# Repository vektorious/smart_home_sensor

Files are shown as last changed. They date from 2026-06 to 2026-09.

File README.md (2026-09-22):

# Smart Home Sensor

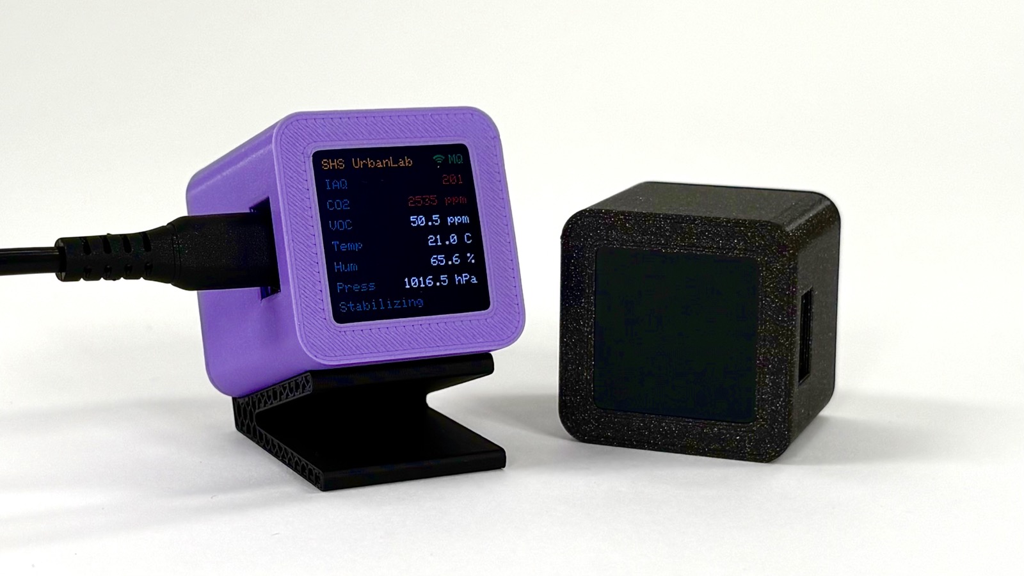
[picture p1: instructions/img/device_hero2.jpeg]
Finished Smart Home Sensor showing live readings on the colour display


An open hardware and firmware kit for a Wi-Fi-connected indoor air-quality sensor, built as a hands-on introduction to microcontroller programming, I2C sensors, air-quality processing, and connecting a DIY device to a smart home system. It is designed to be teachable in a workshop, but the device is meant to stay on a shelf afterwards and keep reporting.

The device reads a Bosch BME680 environmental sensor, runs Bosch's BSEC2 algorithm to derive an air-quality index, shows the live values on a colour display, and publishes them to [Home Assistant](https://www.home-assistant.io/) over MQTT or to the [diy-sensor.org](https://diy-sensor.org) dashboard. The backend is chosen by picking a firmware image at flash time.

Firmware can be built from source with the Arduino IDE, or flashed straight from the browser with the [web flasher](https://alexanderkutschera.com/smart_home_sensor/), which skips the toolchain entirely.

---

## Why This Exists

I wanted a workshop topic that touches sensors, microcontrollers, and IoT all at once, without turning into a semester course. This is the result: a one to two hour teaser that scratches the surface of a lot of things rather than going deep into any single one. None of it is novel, and that is fine. It is meant to be a good starting point.

The build is deliberately not hardwired. The BME680 hangs off four jumper wires, and the board is an ordinary ESP32-C6 with a display. If an air-quality sensor turns out not to be useful to someone, I hope the parts get pulled apart and turned into something else entirely. That would be the better outcome anyway.

---
## What the Device Does

A mains/USB-powered sensor that:
- Measures temperature, humidity, and barometric pressure
- Derives an Indoor Air Quality (IAQ) index, a CO₂-equivalent, and a breath-VOC estimate from the BME680's gas sensor via Bosch BSEC2
- Shows all readings live on the integrated 240×240 colour display, colour-coded by air quality
- Reports every reading to Home Assistant (where it can be charted, automated on, and turned into an "open a window" notification when the air gets stuffy), to plain MQTT topics, or to the diy-sensor.org dashboard, which needs no server of its own

There is no deep sleep and no battery: the live display and BSEC's multi-day gas-sensor self-calibration both need the device to run continuously.

---
## Hardware

- Waveshare ESP32-C6-LCD-1.3 microcontroller (ESP32-C6 + 1.3" ST7789 display)
- BME680 sensor module (temperature, humidity, pressure, gas / air quality)
- 4× Dupont wires (single wires or a 4-pin cable, either works)
- USB-C cable
- _Optional:_ 3D-printed enclosure ([`hardware/3d-print/`](hardware/3d-print/))

There is no custom PCB. The Dupont wires are soldered to the BME680 module's header pads, and their connectors then plug onto the board's pins, so the sensor-to-board link stays removable.

---

## Requirements

For any build:
- A computer with a USB-C port (or adapter)
- A 2.4 GHz Wi-Fi network (the ESP32-C6 will not see a 5 GHz-only network)
- A soldering iron, to solder the Dupont wires to the BME680 module (the only soldering in the build)

For flashing from the browser, that is the whole list: the web flasher needs a browser that supports Web Serial (Chromium, a recent Firefox, Chrome, Edge, or Opera; not Safari).

For the Home Assistant build, additionally:
- A running Home Assistant instance (a Raspberry Pi, mini-PC, or VM is fine)
- The Mosquitto broker add-on and the MQTT integration

To build from source instead of flashing a prebuilt image:
- The [Arduino IDE](https://www.arduino.cc/en/software) with the ESP32 board package and the libraries listed in the build instructions

---

## Documentation

| Guide | Covers |
| --- | --- |
| [`instructions/build_instructions.md`](instructions/build_instructions.md) | The standard build: wiring, browser flashing, setup portal, first readings |
| [`instructions/build_instructions_extended.md`](instructions/build_instructions_extended.md) | Building the firmware from source: Arduino toolchain, BSEC blob, MQTT and Home Assistant |
| [`instructions/background_information.md`](instructions/background_information.md) | BME680 + BSEC, IAQ / CO₂-equivalent / VOC, self-heating and offset calibration, MQTT vs ESPHome, similar projects |
| [`instructions/quick_reference/`](instructions/quick_reference/) | Printable two-page A5 summary |
| [`web-flasher/README.md`](web-flasher/README.md) | Building and publishing the firmware images |

---

## Firmware Variants

One Arduino sketch in [`code/shs_modular/`](code/shs_modular/) builds every image. They all share the display UI, the BSEC read path, and the setup portal, and differ only in where the readings go.

| Image | Reports to | Needs | Suited for |
| --- | --- | --- | --- |
| **diy-sensor.org** | [diy-sensor.org](https://diy-sensor.org), keyless | Wi-Fi | Running without a smart home system, using a hosted dashboard instead |
| **Home Assistant** | MQTT auto-discovery | Wi-Fi, MQTT broker | Keeping the device permanently in an existing smart home |
| **Display only** | nothing | nothing | Checking the hardware before dealing with a network |

Per-device values (device name, broker address, API key, publish interval, temperature offset) all live in the device's flash and are edited from a setup portal the device serves over its own Wi-Fi access point. Nothing needs recompiling per device.

### Workshop images

The build script can also produce a workshop image: the diy-sensor.org firmware with an event's defaults and API credentials compiled in, so the devices come up already pointed at the right dashboard and there is far less to configure on the day. The presets are only defaults, and the setup portal still overrides them. This is why the sketch builds four images rather than three. See [`web-flasher/README.md`](web-flasher/README.md) for how such an image is built and why its credentials stay out of the publicly served ones.

### ESPHome alternative

[`code/esphome/`](code/esphome/) holds an ESPHome configuration for the same hardware: native Home Assistant API, no broker, minimal display. Not yet verified on hardware.

---

## Repository Structure

```
code/
  shs_modular/             Firmware (Arduino + BSEC2 + display + backends)
    config.h               Pins, build variant, factory defaults — no credentials
    workshop_secrets.example.h  Template for the workshop API key (copy, gitignored)
    shs_modular.ino        Entry point
    settings.ino           Runtime settings in NVS + derived device identity
    portal.ino             Setup portal: Wi-Fi, settings, live readings, send test
    resetdetect.ino        Double-reset detection (re-opens the portal)
    display.ino            ST7789 UI
    bme680.ino             BME680 read path via Bosch BSEC2
    wifi.ino               Station connect + background reconnect
    mqtt.ino               MQTT: HA auto-discovery / flat topics / both
    sensorboard.ino        HTTPS publishing to diy-sensor.org
    utils.ino              Shared helpers
    bsec_config_33v_3s_4d.h  BSEC tuning blob (3.3 V, 3 s sample rate)
  esphome/
    smart_home_sensor.yaml Alternative ESPHome firmware
  legacy/
    test_wv_display/       Original display+sensor sketch (no networking, reference)

web-flasher/               Browser-based installer (ESP Web Tools) + build.sh

hardware/
  3d-print/                Enclosure parts (Main/thin body, lid, FreeCAD source)

instructions/
  build_instructions.md    Standard build guide — start here
  build_instructions_extended.md  Arduino toolchain, building from source, MQTT
  background_information.md Sensor theory, IAQ explained, MQTT vs ESPHome, system overview
  quick_reference/         One-page summary

img/                       Photos and diagrams (TODO)
```

---

## Licenses

| Component | License |
|---|---|
| Software (`code/`) | [MIT](LICENSE.code) |
| Hardware (`hardware/`) | [CERN-OHL-W 2.0](LICENSE.hardware) |
| Documentation (`instructions/`, `README.md`, `img/`) | [CC-BY 4.0](LICENSE.docs) |

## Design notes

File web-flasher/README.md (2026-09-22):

# Smart Home Sensor — Web Flasher

A browser-based installer built on [ESP Web Tools](https://esphome.github.io/esp-web-tools/).
Students open a page, pick a firmware, click **Connect**, and flash the board — no
Arduino IDE and no drivers.

## Files

| File | Purpose |
|---|---|
| `index.html` | The flasher page: firmware picker + install button |
| `manifest-workshop.json` | HPI Makeruniverse Welcome Workshop — keyed, time-limited |
| `manifest-sensorboard.json` | diy-sensor.org, keyless — the standard build |
| `manifest-ha.json` | Home Assistant over MQTT |
| `manifest-display.json` | Display only, no networking |
| `build.sh` | Builds all four images into `firmware/` |
| `vendor/` | ESP Web Tools, served from this site rather than a CDN (see `vendor/README.md`) |
| `firmware/*.bin` | Merged images (generated; gitignored on `main`) |

## The four images

All four come from the same sources in `code/shs_modular/`. None carries per-device
configuration: that lives in NVS and is entered in the setup portal after flashing,
which is what lets one image serve a whole room.

| Image | Build flags | Backend | Needs |
|---|---|---|---|
| **workshop** | `SHS_VARIANT=2` | diy-sensor.org, keyed | nothing — a Wi-Fi network |
| **sensorboard** | `SHS_VARIANT=2 SHS_NO_WORKSHOP_SECRETS` | diy-sensor.org, keyless | nothing |
| **ha** | `SHS_VARIANT=1` | MQTT auto-discovery | a broker + the HA MQTT integration |
| **display** | `SHS_VARIANT=3` | none | nothing |

`workshop` and `sensorboard` are the *same* variant and differ only in whether
`workshop_secrets.h` is compiled in — `SHS_NO_WORKSHOP_SECRETS` forces the keyless
build even on a machine that has the header, so both come out of one run of
`build.sh`. The include is also gated on `USE_SENSORBOARD`, which keeps the
credentials out of the `ha` and `display` images: those still copy
`DEFAULT_API_KEY` into settings, so without the gate the literal would be linked
into two binaries that have no use for it and are served publicly.

`build.sh workshop` refuses to run without `workshop_secrets.h` rather than quietly
producing an anonymous binary that calls itself the workshop image.

## Requirements (for whoever is flashing)

- A desktop browser with **Web Serial**: **Chromium**, a **recent Firefox**, Chrome, Edge, or Opera. It does not exist in older Firefox or
  Safari, or anywhere on iOS.
- The page must be served over **HTTPS** (or `http://localhost`). Web Serial refuses
  to run on plain `http://`.
- A USB-C **data** cable.

## Building the images

```bash
./build.sh                 # all four
./build.sh sensorboard     # just one
```

The script needs `arduino-cli` with the `esp32` core and the libraries listed in
[`instructions/build_instructions.md`](../instructions/build_instructions.md). It
creates the missing `esp32c6` BSEC blob automatically if a library update has
removed it — that failure otherwise surfaces as a bare linker error.

Each build is one merged image flashed at offset `0x0`; the ESP32 Arduino core emits
it as `shs_modular.ino.merged.bin`, so no `esptool merge_bin` step is needed. The
**Huge APP (3MB No OTA/1MB SPIFFS)** partition scheme is required — the default is
too small for BSEC.

After building, bump `"version"` in the matching manifest so returning users are
offered the update.

### Doing it by hand in the Arduino IDE

1. Set `SHS_VARIANT` in `config.h`.
2. Board **ESP32C6 Dev Module**, **Tools → Partition Scheme → Huge APP**.
3. **Sketch → Export Compiled Binary**, then copy `build/…/shs_modular.ino.merged.bin`
   to `web-flasher/firmware/shs-<image>.bin`. For the keyless build, add
   `SHS_NO_WORKSHOP_SECRETS` to the sketch's build flags or temporarily move
   `workshop_secrets.h` aside.

## Workshop image

The HPI Makeruniverse Welcome Workshop runs on **23–24 September 2026**.
Its dashboard project is `hpi-makeruniverse-welcome-workshop`, and its image
is scheduled for withdrawal on **1 October 2026**. Withdrawal is a manual
publication step; the date shown on the page does not remove the image automatically.

Built against the gitignored `code/shs_modular/workshop_secrets.h` (see
`workshop_secrets.example.h`), which bakes in an API key, the dashboard project, and
the salt each device derives its write key from.

**Why it carries a key at all.** Not for persistence — that is switched *off* for the
workshop policy. It is the per-IP limits: a class sits behind one NAT address, and the
anonymous policy allows 10 active devices, 5 new devices an hour, and 1,000 requests a
day. A keyless class of 80 boards would stop at the fifth. With a key those become
500 / 100 / 50,000.

**Treat it as a temporary artefact.** Anything in that header is inside a binary served
publicly, so `strings` recovers it in seconds. The **API key** is therefore effectively
published: anyone who downloads the image can write to the instance under the workshop
policy, and because the write budget is charged per credential they can drain the same
bucket the class draws from.

The **salt** is weaker than it looks, but not as weak as "the key is public":

- The write key is `HMAC-SHA256(salt, mac)` over the **full 48-bit MAC**, while the
  public device ID carries only the low 32 bits — and those are the OUI plus one NIC
  byte, the predictable part. A device ID therefore leaves 2^16 = 65,536 candidates,
  with no offline way to test one: each guess costs a POST. Under the per-IP limits
  that is hours per device and a wall of 403s in the ingest log.
- Proximity defeats it entirely. The ESP32's Wi-Fi station MAC **is** the base efuse
  MAC — the exact derivation input — broadcast in the clear in every frame. Anyone in
  radio range reads all 48 bits passively, without joining the network.

Inherent to deriving from the MAC; no salt scheme changes it, and it is the price of a
key that survives a flash erase so a student cannot brick their device ID. For a
classroom it is a prank vector, not a breach.

### Retiring it

The page states a withdrawal date, and the date is the point:

1. delete `manifest-workshop.json` and `firmware/shs-workshop.bin` from `gh-pages`,
   and drop the option from `index.html`;
2. remove the key from `API_KEYS` in the server `.env` and restart the service;
3. `python -m app.admin delete-key-data <sha256>` for anything left behind.

With `POLICY_<NAME>_PERSISTENT_DEVICES=false` step 3 is mostly a formality: the
devices expire 48 h after their last reading on their own.

**Set that policy before the first board claims its ID.** `persistent` is a column
stamped at creation (`routes/ingest.py`: `persistent=authenticated and
policy.persistent_devices`) and the sweep reads the column, not the current policy.
Applied afterwards it changes nothing for devices that already exist: they stay
persistent forever, are never swept, and their IDs never become claimable again
without deleting them by hand.

Students keep their hardware: the keyless **sensorboard** image stays on the page and
publishes to the same dashboard. It claims the same device ID, so if the workshop
device has not expired yet, paste the write key shown on the workshop portal page into
the keyless build's *Write key* field to adopt it. After expiry the ID is simply free
again.

## Hosting

GitHub Pages publishes from a branch root or `/docs`, not an arbitrary subfolder, so
the site lives on a dedicated `gh-pages` branch mirroring this folder at its root:

```
gh-pages/
├── index.html
├── vendor/                    # ESP Web Tools (26 files + LICENSE)
├── manifest-workshop.json
├── manifest-sensorboard.json
├── manifest-ha.json
├── manifest-display.json
├── .nojekyll
└── firmware/
    ├── shs-workshop.bin
    ├── shs-sensorboard.bin
    ├── shs-ha.bin
    └── shs-display.bin
```

The binaries live only on `gh-pages` — four 4 MB images per release would bloat
`main`'s history for no benefit, which is why `firmware/.gitignore` excludes them.

```bash
git worktree add /tmp/ghpages gh-pages
cp index.html manifest-*.json /tmp/ghpages/
cp -r vendor /tmp/ghpages/
cp firmware/*.bin /tmp/ghpages/firmware/
# bump "version" in the manifests you changed
git -C /tmp/ghpages commit -am "Update flasher firmware" && git -C /tmp/ghpages push
git worktree remove /tmp/ghpages
```

## Local testing

```bash
python3 -m http.server 8000
# open http://localhost:8000 — localhost counts as secure for Web Serial
```

## Setup AP names

The commissioning AP uses a deterministic, friendly name such as
`SHS-Sparkly-Capybara`. The adjective and noun are selected from the ESP-IDF
base MAC, so the same board gets the same name after reboot while boards with
different base MACs normally get different names. The generated name is used
only for the temporary setup AP; the persisted device name and dashboard name
are unchanged.

The word lists are original project content and live in
`code/shs_modular/ap_names.h`. They are compiled into flash and contain no
external data or runtime dependency.

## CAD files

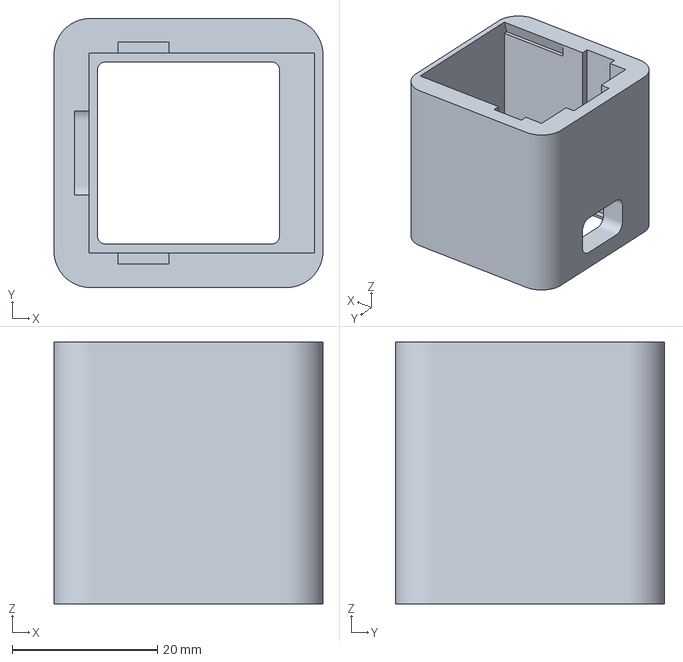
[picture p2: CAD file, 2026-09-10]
hardware/3d-print/SmartHomeCube-Main.3mf
37.0 x 37.0 x 36.0 mm

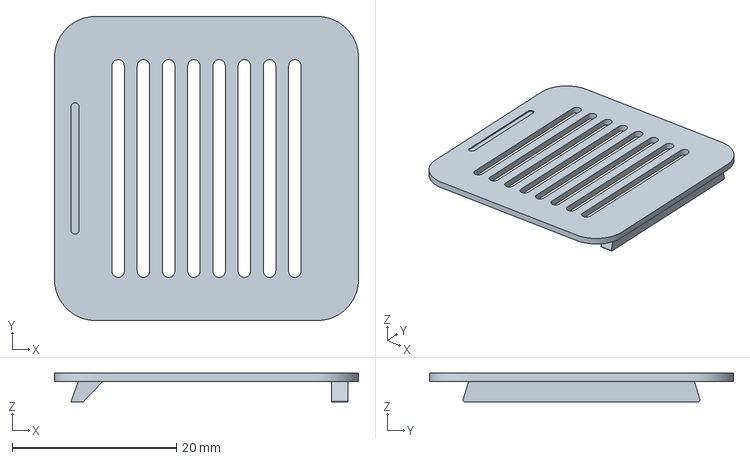
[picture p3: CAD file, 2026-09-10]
hardware/3d-print/SmartHomeCube-Lid.3mf
37.0 x 37.0 x 3.50 mm

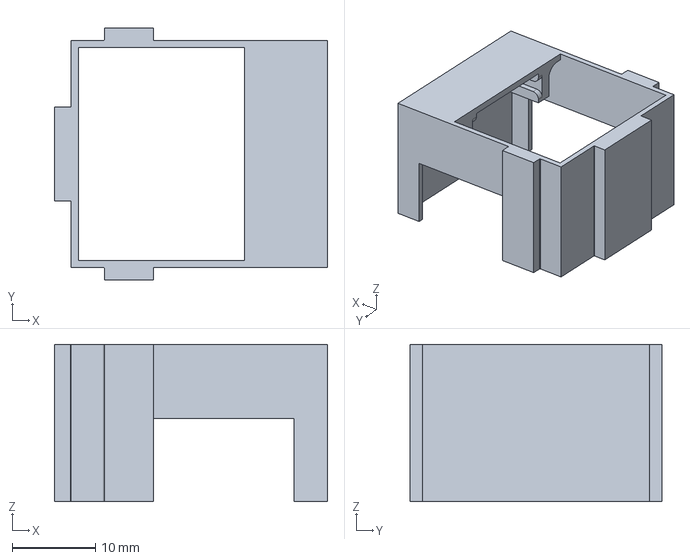
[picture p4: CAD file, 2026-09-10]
hardware/3d-print/src/SmartHomeCube.FCStd
32.8 x 30.3 x 18.9 mm

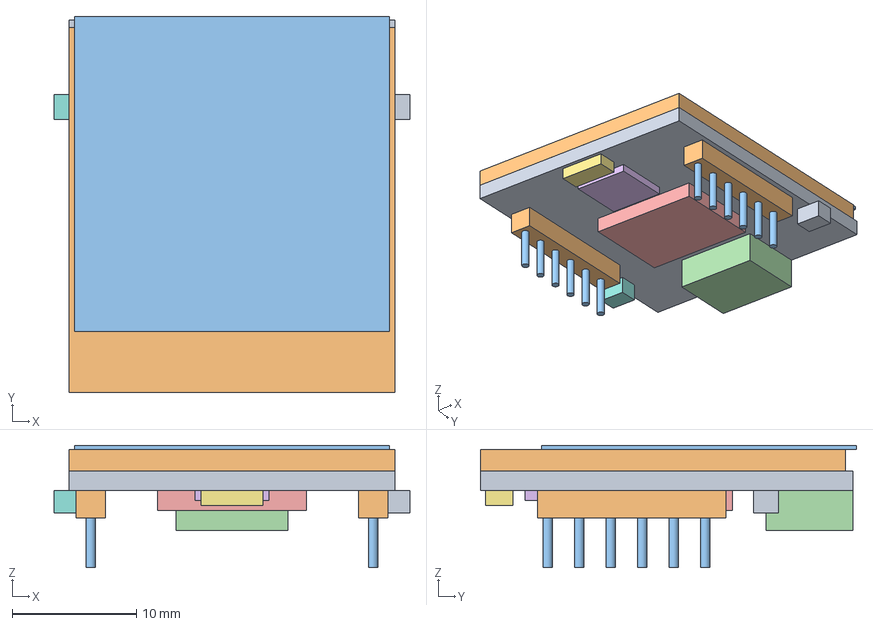
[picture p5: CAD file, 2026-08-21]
hardware/3d-print/src/ESP32-C6-LCD-1.3-M.FCStd
28.6 x 30.3 x 9.85 mm
PCB
LCD frame
LCD glass
USB-C connector
MicroSD slot
ESP32-C6FH4
Ceramic antenna
RESET button
BOOT button
Header plastic
Header pins
M2 mounting holes

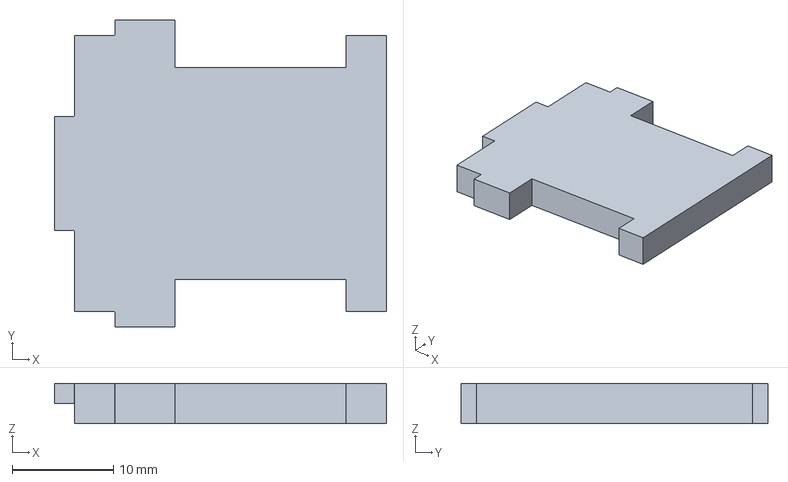
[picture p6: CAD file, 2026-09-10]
hardware/3d-print/SmartHomeCube-Inlay_mid.3mf
32.8 x 30.3 x 4.00 mm

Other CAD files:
hardware/3d-print/SmartHomeCube-Inlay_top.3mf

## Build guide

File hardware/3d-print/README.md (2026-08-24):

# 3D-Printed Enclosure

An enclosure for the Waveshare ESP32-C6-LCD-1.3 + BME680 that keeps the display visible,
gives the BME680 airflow while shielding it from the warm side of the board, and routes the
USB-C cable for permanent powered operation.

## Assembly

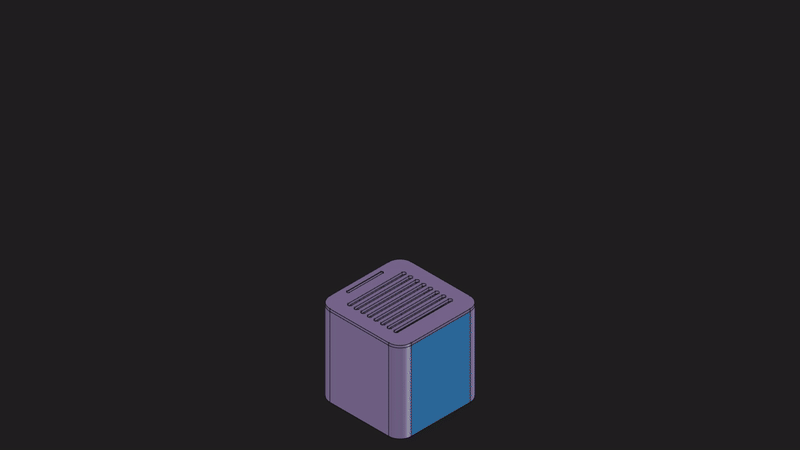
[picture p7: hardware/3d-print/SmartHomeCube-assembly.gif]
Exploded assembly animation


The enclosure is assembled from bottom to top in this order:

1. Main housing
2. ESP32-C6-LCD-1.3-M
3. Lower inlay
4. Upper inlay
5. Lid

The higher-quality MP4 version is available as [`SmartHomeCube-assembly.mp4`](SmartHomeCube-assembly.mp4).

## Parts

| File | Description | |
|---|---|---|
| `SmartHomeCube-Main.3mf` | Main body | required |
| `SmartHomeCube-Inlay.3mf` | Lower inlay, sits on the board and carries the sensor above it | optional |
| `SmartHomeCube-Inlay_top.3mf` | Upper inlay, holds the BME680 under the lid opening | optional |
| `SmartHomeCube-Lid.3mf` | Lid | required |

The two inlays position the BME680 above the board and away from its heat. Without them the sensor still works, but something insulating should go between board and sensor instead, for example the styrofoam packing piece the ESP32 board ships with.

Print with standard PLA settings; no supports needed.

## Modifying the fit

The FreeCAD source is in `src/SmartHomeCube.FCStd`. All clearances and offsets are exposed in
the **Variable set** (`Model → Variable set`) so you can adjust them for a tight fit without
touching the geometry directly.

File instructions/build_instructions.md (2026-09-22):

# Build Instructions: Smart Home Sensor

This is the standard build. You solder four wires to the BME680, connect it to the board, flash a prebuilt firmware image from your browser, and configure the device through its own setup page. No Arduino IDE, no libraries and no account needed.

**What you need:**

The ESP board, the BME680, four Dupont wires, a USB-C data cable, a soldering iron, and a laptop running a browser that supports Web Serial: Chromium, a recent Firefox, Chrome, Edge, or Opera. Older Firefox versions do not have it, and neither does Safari or anything on an iPad.

---

## 1. Collect all parts

**Electronics**

- Waveshare ESP32-C6-LCD-1.3 microcontroller (ESP32-C6 + 1.3" ST7789 display)
- BME680 sensor module
- 4× Dupont wires (single wires or a 4-pin cable, either works)
- USB-C data cable (a charge-only cable cannot flash the ESP, and they look identical)

**Optional**

- 3D-printed enclosure, see [`hardware/3d-print/`](../hardware/3d-print/)

**Tools**

- A computer with a USB-C port
- Soldering iron and solder

---

## 2. Wire the sensor

The BME680 talks to the board over **I2C**: two data lines plus power and ground.

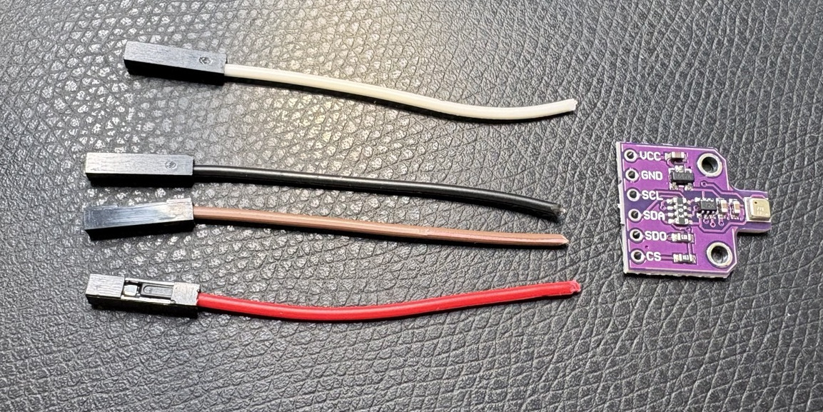
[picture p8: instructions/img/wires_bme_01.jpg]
Four Dupont wires and the BME680 module before assembly


Cut one end off each Dupont wire and strip about 3 mm of insulation. Twist the exposed copper strands together. Keep the female socket on the other end; it plugs onto the board's header pins.

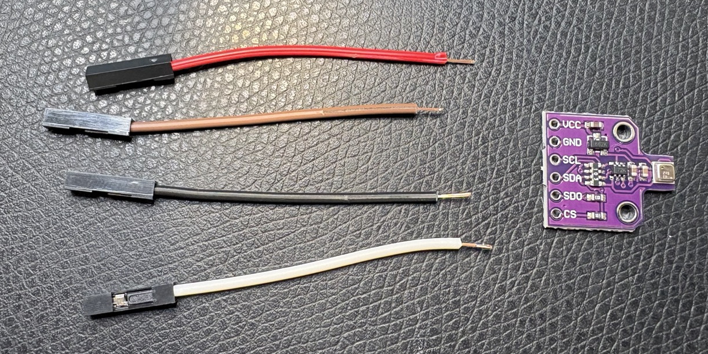
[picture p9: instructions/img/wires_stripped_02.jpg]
The four wires cut and stripped, ready to solder


Use the four pads labelled **VCC, GND, SDA, and SCL**. Push each stripped end through its hole **from the back**, the plain side without the components, and bend it flat against the labelled front so the wire runs off the side edge of the module, in the plane of the board. Soldering them this way keeps the wires out of the way of both the sensor and the enclosure.

<div align="center">

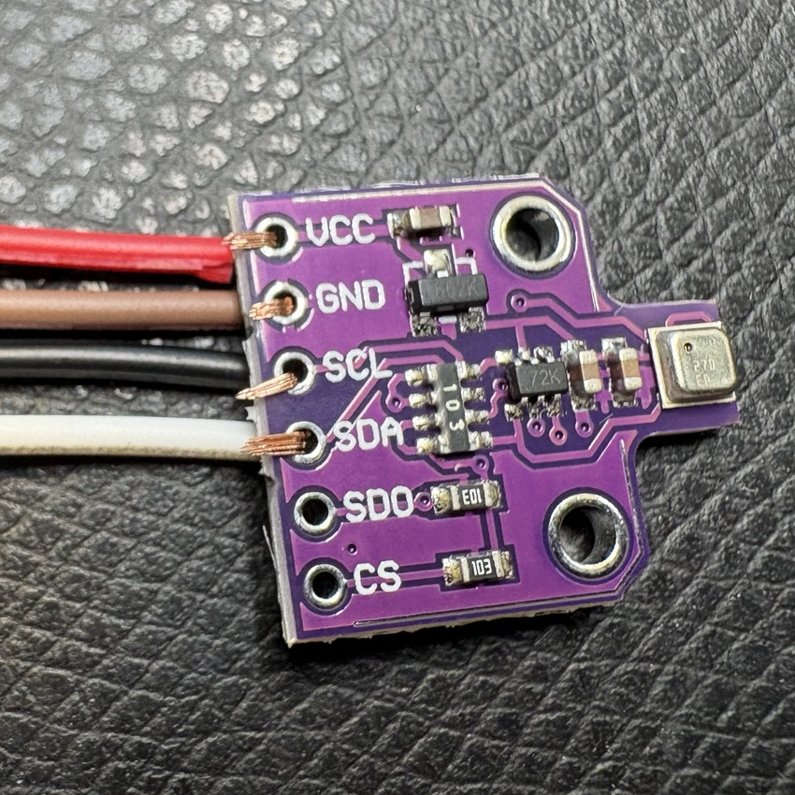
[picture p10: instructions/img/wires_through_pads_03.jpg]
Stripped wire ends pushed through the pad holes and bent flat, before soldering


</div>

Solder each joint on that labelled side, then snip off anything sticking out past the pad.

<div align="center">

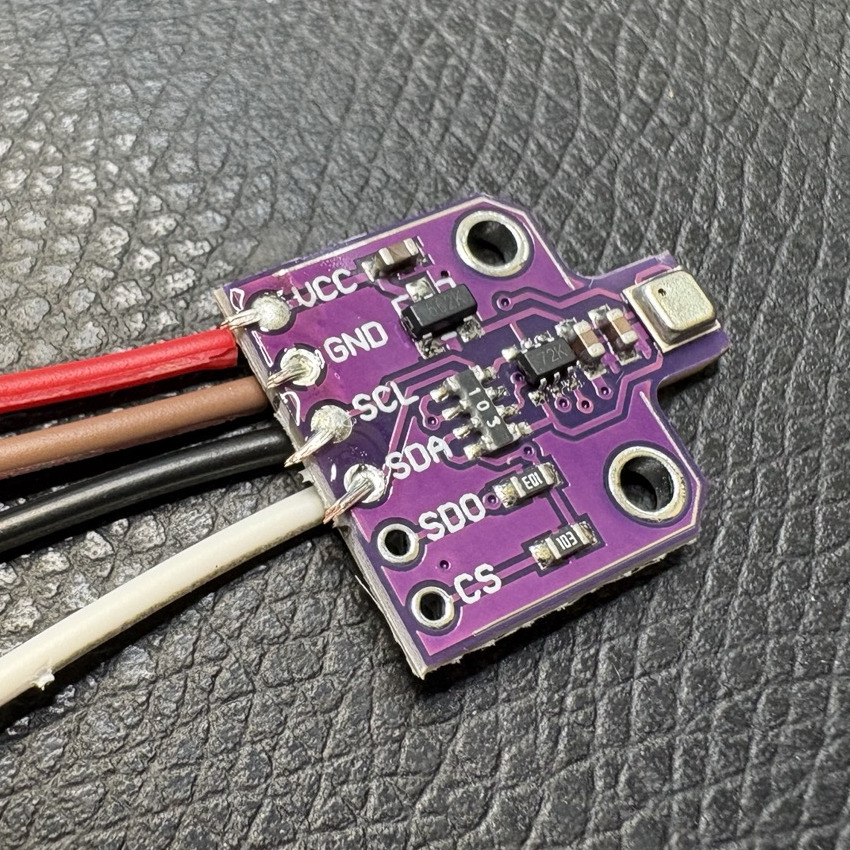
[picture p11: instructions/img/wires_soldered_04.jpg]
The four wires soldered to the BME680 pads, wires leaving flat to the side


</div>

<div align="center">

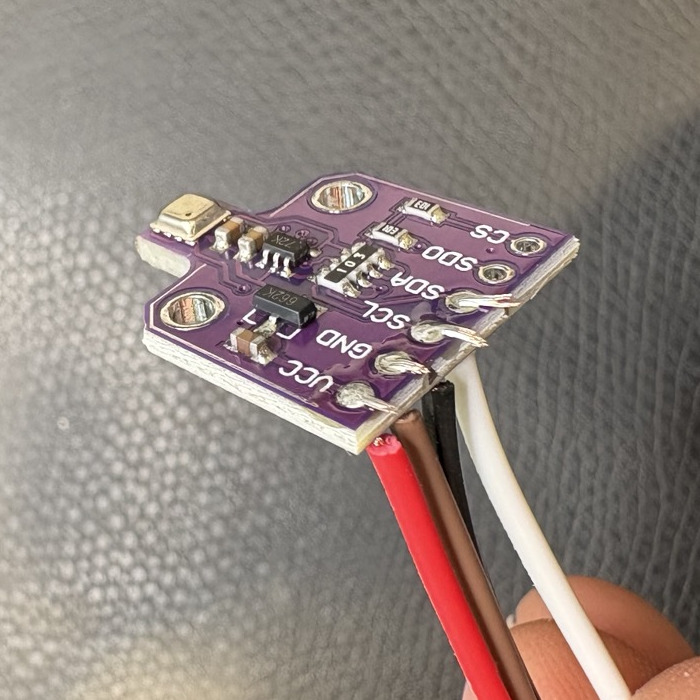
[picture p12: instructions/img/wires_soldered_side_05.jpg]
Side view of the soldered joints, showing the wires staying in the plane of the module


</div>

Then push the four sockets onto the matching pins on the board. Only the sensor side is soldered, so the sensor-to-board link stays removable and the board can be reused for something else later.

Before plugging in the USB cable, check that VCC connects to **3V3, not 5V**, and that SDA and SCL are not swapped. Swapping those two signal wires is a common reason the board cannot detect the sensor.

| BME680 pin | VCC | GND | SDA | SCL |
| --- | --- | --- | --- | --- |
| Board pin  | 3V3 | GND | GPIO 3 | GPIO 2 |

<div align="center">

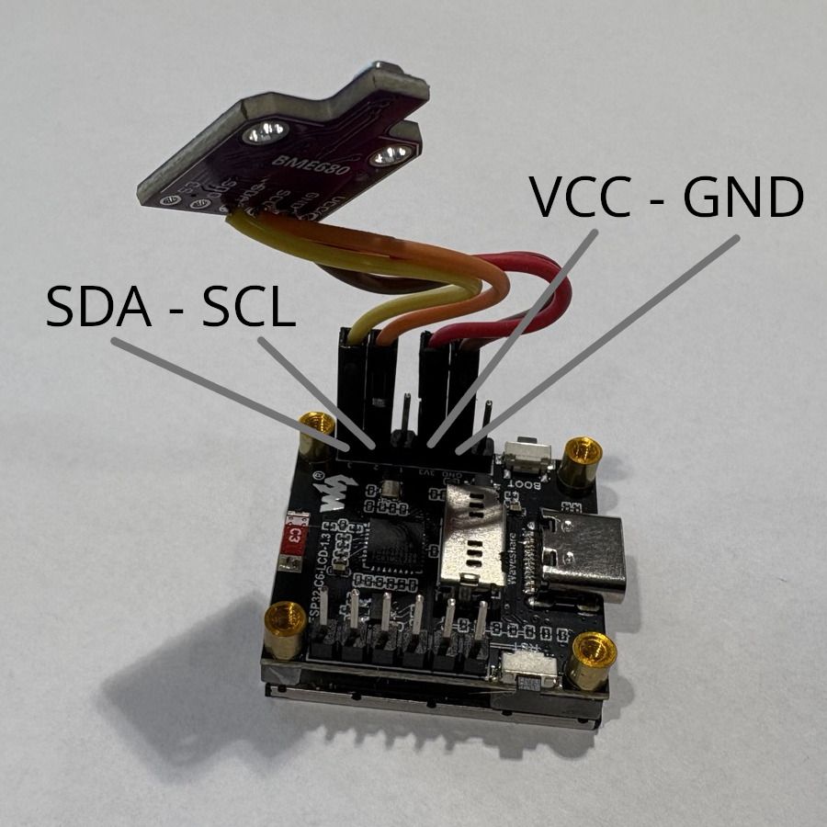
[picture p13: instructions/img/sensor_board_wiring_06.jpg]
BME680 sensor connected to the board, with the SDA/SCL and VCC/GND connections labelled


</div>

---

## 3. Flash and test the sensor

Before putting the board into the enclosure, flash it and verify that the wired BME680 is working. Wiring problems are much easier to fix while the board and sensor are still accessible.

1. Open the [web flasher](https://alexanderkutschera.com/smart_home_sensor/).
2. Pick an image. In a workshop, choose the one your instructor recommends: it usually carries the event's dashboard settings already, so there is less to fill in later. Otherwise pick **diy-sensor.org** to publish to the public dashboard, or **Home Assistant (MQTT)** if you already run Home Assistant with an MQTT broker.
3. Plug the board into your laptop with a USB-C data cable.
4. Click **Connect**, choose the port named `USB JTAG/serial debug unit`, and click **Install**. It takes about a minute.

If the port list is empty, start the board in flashing mode: unplug it, hold **BOOT**, plug the cable back in while holding the button, then release it after about 2 seconds. If the board still does not appear, try another USB data cable.

When flashing finishes, let the board boot with the sensor still connected. On the setup display, wait for the **BME680 sensor** indicator to show green **OK**. It may show **checking...** or **warming up** first. That is all you need to check at this stage; you will look at live readings after setup.

> **Stop here if the sensor is not detected.** Switch off USB power and re-check the wiring: 3V3 (not 5V), GND, SDA → GPIO 3, and SCL → GPIO 2. Reseat the connectors and test again. Do not put the board into the enclosure until this check passes.

---

## 4. Assemble the enclosure

If you printed the enclosure, assemble it now. It keeps the display visible and holds the BME680 above the board, away from the heat the ESP32 and the backlight give off, which can otherwise distort the temperature and humidity readings (see [`background_information.md`](background_information.md)).

Exploded assembly animation

<div align="center">

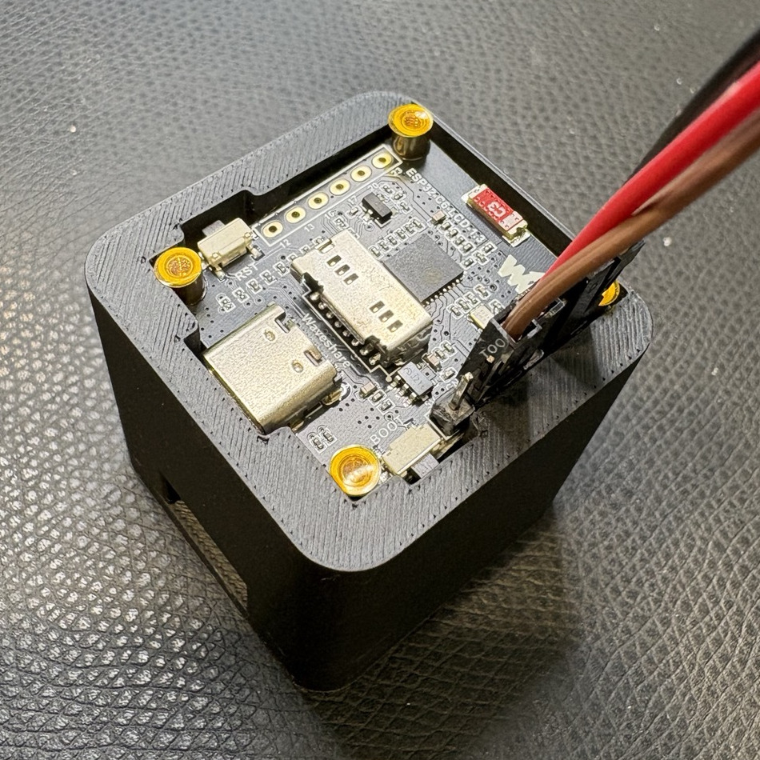
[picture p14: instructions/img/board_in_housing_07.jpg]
BME680 connected to the Waveshare board, which is resting on the open enclosure


</div>

Assemble from bottom to top:

1. **Main housing**: the outer body.
2. **ESP32-C6-LCD-1.3 board**: display facing the open front.
3. **Lower inlay**: separates the board from the sensor above it.
4. **Upper inlay**: holds the BME680 under the lid.
5. **Lid**: snaps on, but does not drop straight down. See *Closing the lid* below.

The two inlays are optional. In any case, put something insulating between the board and the sensor: the small piece of styrofoam the ESP32 board ships with does the job, so keep it when you unpack the board.

**Board and lower inlay.** Drop the board into the main housing with the display facing the open front (the bottom), and feed the sensor wires out past it. Lay the lower inlay on top of the board, then press board and inlay down together until they sit at the bottom of the housing. Leave the BME680 itself outside for now.

<div align="center">

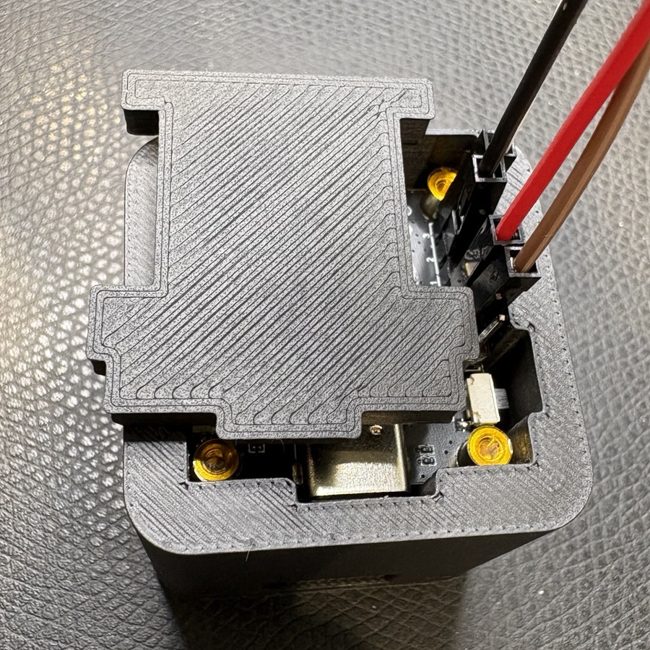
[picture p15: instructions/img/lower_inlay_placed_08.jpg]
Lower inlay laid on top of the board, both still standing proud of the housing


</div>

<div align="center">

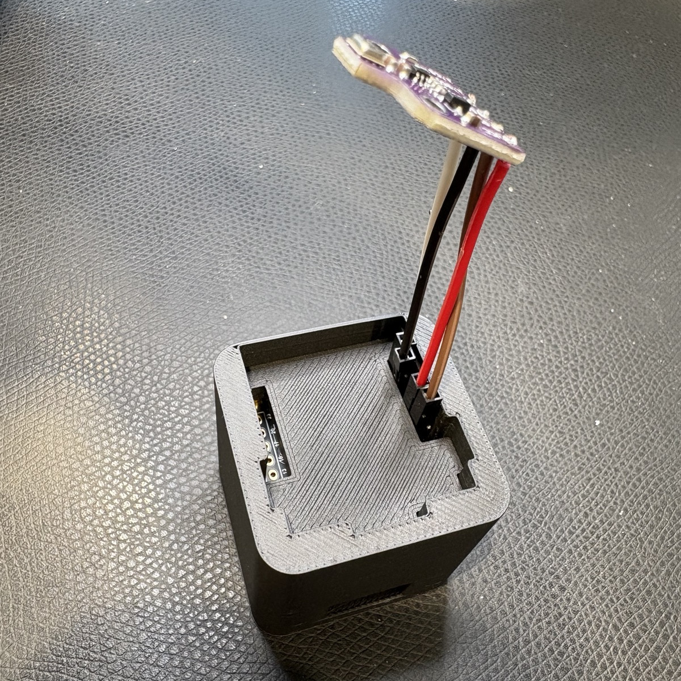
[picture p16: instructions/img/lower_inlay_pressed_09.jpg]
Board and lower inlay pressed further in, the sensor still hanging outside


</div>

<div align="center">

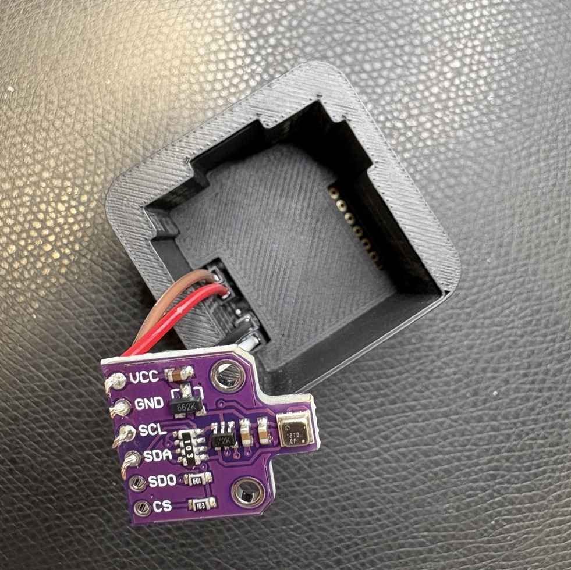
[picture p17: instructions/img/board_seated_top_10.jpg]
Top view with board and lower inlay seated at the bottom, sensor still out


</div>

**Sensor and upper inlay.** The BME680 drops into the recess in the upper inlay with its **component side facing up**, towards the lid grille, so the sensor breathes room air instead of the air trapped over the board. The wires leave through the side opening.

<div align="center">

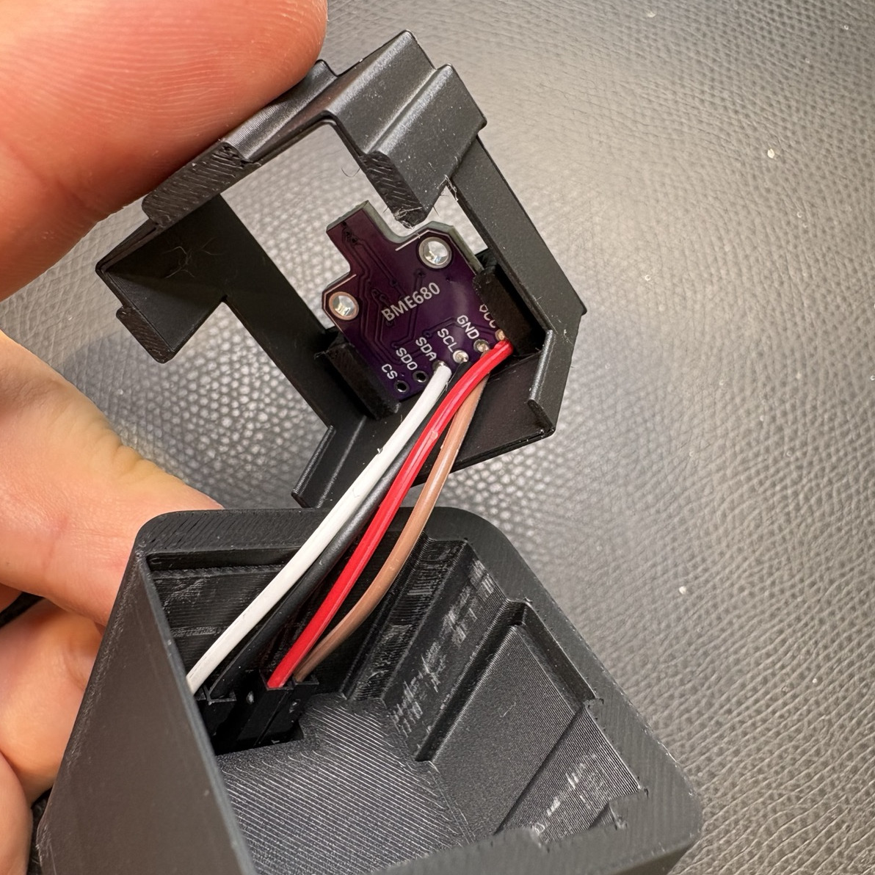
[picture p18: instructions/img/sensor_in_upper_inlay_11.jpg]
BME680 seated in the upper inlay, component side towards the lid, wires led out the side


</div>

Lay the styrofoam over the back of the sensor. It fills the space between sensor and board and reduces heat transfer from the ESP32.

<div align="center">

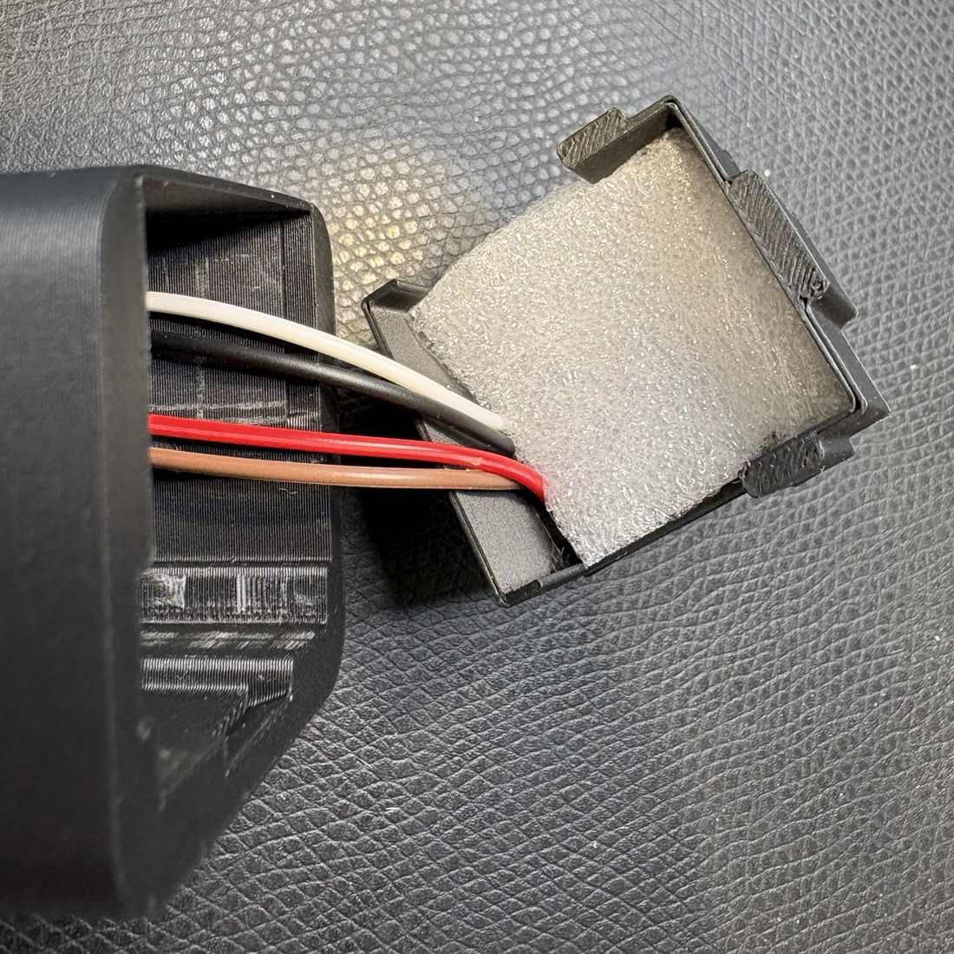
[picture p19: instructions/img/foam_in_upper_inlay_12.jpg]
Styrofoam laid into the upper inlay behind the sensor as a heat shield


</div>

Now lower the whole upper inlay into the housing, tucking the slack wire in as you go, and press it down until it sits flush.

<div align="center">

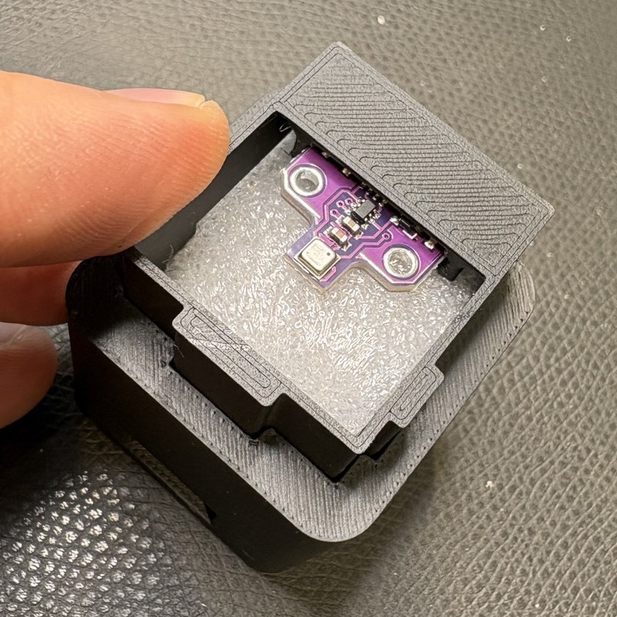
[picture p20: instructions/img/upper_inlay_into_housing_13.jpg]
Upper inlay with sensor and foam going into the main housing


</div>

<div align="center">

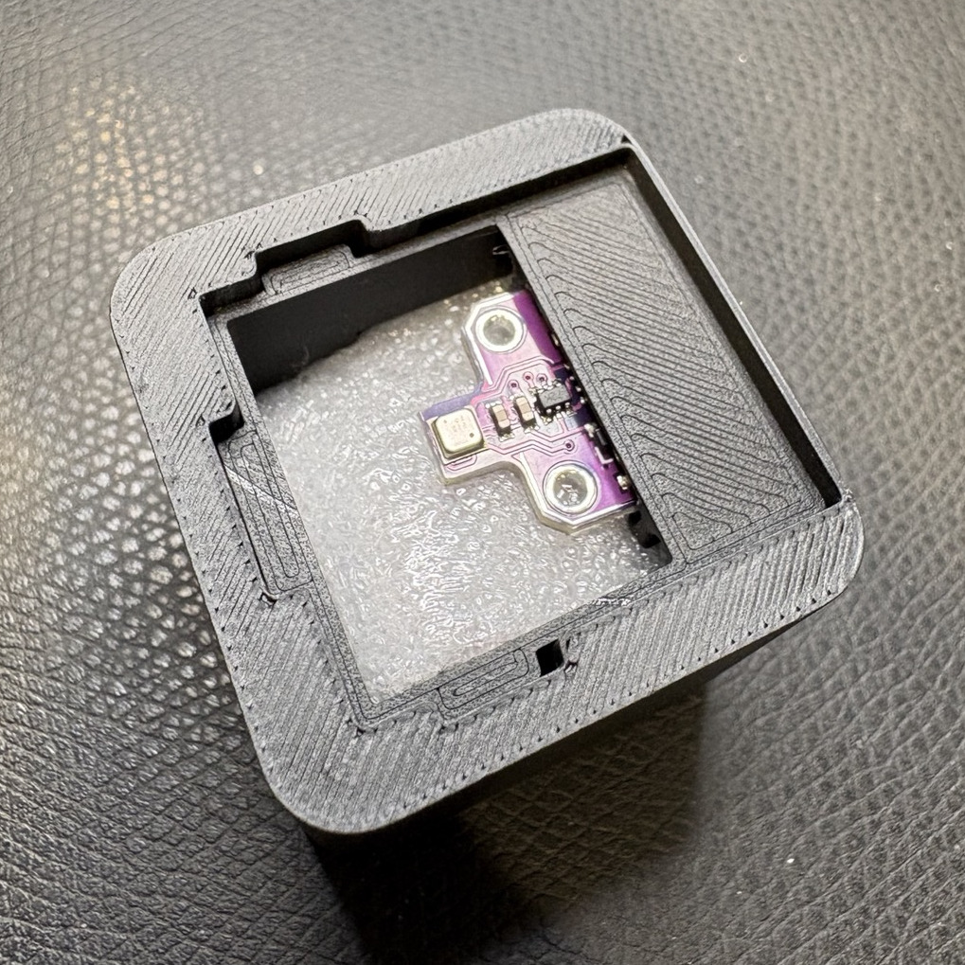
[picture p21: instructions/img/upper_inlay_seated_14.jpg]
Upper inlay seated, sensor facing up ready for the lid


</div>

**Closing the lid.** The lid does not press on from straight above. One edge carries a long tab, the opposite edge a short one, and they go in one after the other. Hold the lid at a slight angle, as in the photo, and slide the long tab into the two rails inside the main body. With that edge held in the rails, lower the other edge until the short tab snaps into its notch and the lid sits flush. To open it again, release the short tab first and then draw the long tab back out of the rails, rather than prying the lid straight up.

<div align="center">

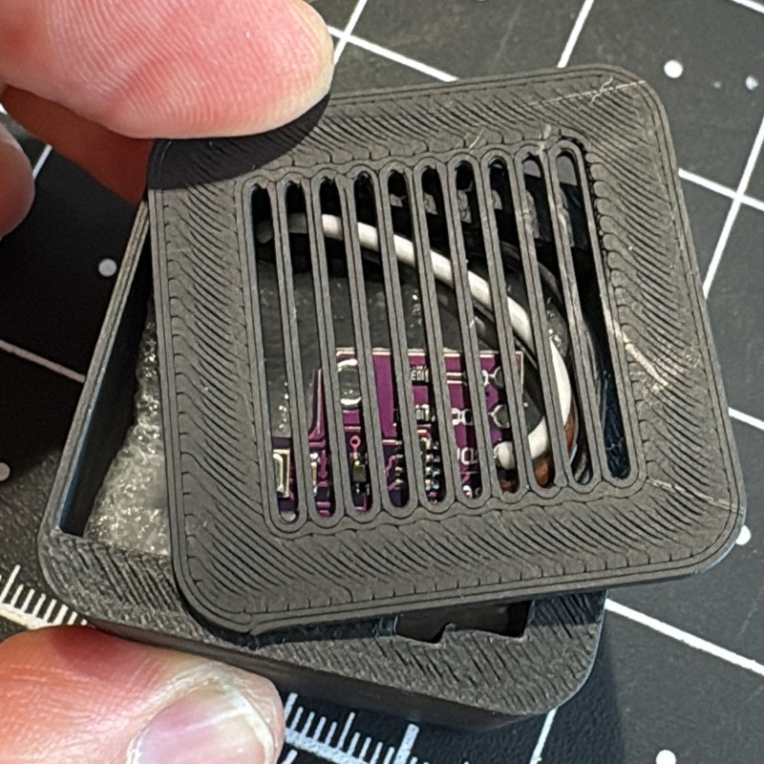
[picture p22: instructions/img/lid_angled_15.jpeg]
Lid held at an angle, its long tab going into the rails in the main body first


</div>

<div align="center">

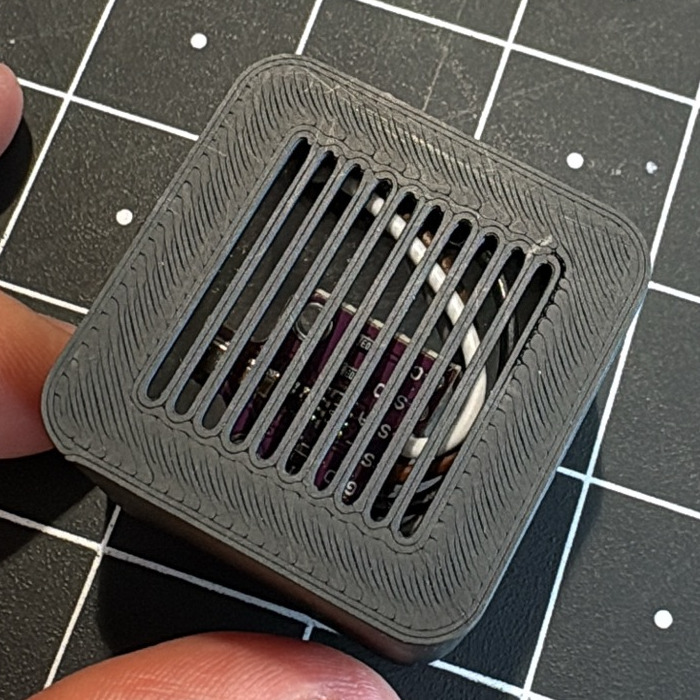
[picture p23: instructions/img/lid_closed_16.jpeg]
Lid closed flush, the BME680 visible through the grille


</div>

Once closed, the BME680 sits directly beneath the lid grille, exposed to room air rather than to heat from the board.

*(Some parts in these photos were printed in a different colour than the rest of the enclosure.)*

Print files and FreeCAD source: [`hardware/3d-print/`](../hardware/3d-print/).

---

## 5. Set it up

The board is already flashed and the sensor was checked in step 3. After assembling the enclosure, reconnect USB power. The display shows **Setup mode** with a Wi-Fi network name and an address.

1. On your laptop or phone, join the Wi-Fi network shown on the display. It has a friendly name such as **`SHS-Bouncy-Alpaca`**. It has no password.
2. A setup page should open by itself. If not, browse to **`192.168.4.1`**.
3. Tap **Configure WiFi**, pick the network, enter the password, and save. Every page here is served by the sensor itself, so give it a few seconds. Saving the Wi-Fi credentials takes longer because the board connects to the selected network. Tapping a second time only queues a second request. If your network is missing, check that it supports **2.4 GHz**. The ESP32-C6 cannot connect to a 5 GHz-only network.
4. Go back to the setup page and open **Setup** to give your device a **name**. On a shared dashboard this is what everyone else sees, so make it recognisable. Save.
5. Open **Live readings & connection test** and press **Send a test reading**.

On a diy-sensor.org image, a green **✓ 201** with **reading stored** means the server accepted your reading and the device is ready. Press the button again and you will see **200** instead: 201 means the device claimed its ID with that first reading, 200 that it added another. Both mean stored.

On a Home Assistant image, enter the broker host, port, and credentials under **Setup** and save them before sending a test reading. The test checks the connection to your broker. Further MQTT instructions are in [`build_instructions_extended.md`](build_instructions_extended.md).

Press **Finish setup** when the test passes. The portal also closes on its own after 10 minutes.

> Your **device ID** is printed on the display and on the setup page. The default ID is derived from the chip and stays the same across resets and reflashes. You can override it under **Setup**; a factory reset restores the default ID.

> **To change a setting later**, press **RESET twice in quick succession**. The display tells you when the window is open, then setup mode returns. This is how you move the device to another network, correct the temperature offset, or point it somewhere else, without reflashing.

> ⚠️ **The current enclosure covers the RESET button.** Until a revised case opens it up, reaching it means sliding the board out of the housing. You can also enter setup without using the button: at power-up, the device opens setup mode if it cannot connect to a saved Wi-Fi network. Power it up out of range of the saved network, or with that network switched off. Then join the setup Wi-Fi network shown on the display. (A network that drops *while* the device is running does not reopen setup; it reconnects in the background instead.)

---

## 6. Find your readings

**diy-sensor.org images:** go to `diy-sensor.org/dashboard/device/<your-device-id>`, or find your device name in the project your instructor points you at.

**Missed the QR code or don’t know your device ID?** You can always open [diy-sensor.org/dashboard](https://diy-sensor.org/dashboard) and look for your device by the name you gave it during setup. Select it to open its readings.

**Home Assistant images:** the device appears by itself under *Settings ▸ Devices & Services ▸ MQTT*, with entities for IAQ, IAQ Accuracy, CO₂ equivalent, Breath VOC equivalent, Temperature, Humidity, and Pressure.

Readings are sent every **5 minutes** by default, so the first chart takes a little patience. The display updates every few seconds regardless, which is where to look for an immediate reaction. You can shorten the interval in the setup page, but on a shared workshop key every device's readings come out of the same budget, so leave it unless you have a reason.

---

## 7. Now make it read something

The gas sensor is the interesting part, and it needs to warm up. Try these while it does:

- **Breathe on the sensor** from a few centimetres away and watch VOC and CO₂-equivalent climb, then fall back over a minute or two.
- **Compare temperature** against a separate thermometer after the device has warmed up for 20–30 minutes. Yours will read high: the ESP32 and the backlight warm the sensor board. The setup page has a **Temperature offset** field to correct it. It already defaults to 5 °C, so add whatever error is left to that number rather than replacing it. If the display still reads 2.5 °C high, the offset becomes 7.5, not 2.5.
- **Watch IAQ accuracy.** It starts at 0 and works up to 3. Until it reaches 3, treat the IAQ value as provisional while BSEC learns the air-quality baseline in your room. Reaching 3 takes hours, and full convergence takes up to four days of running.

<div align="center">

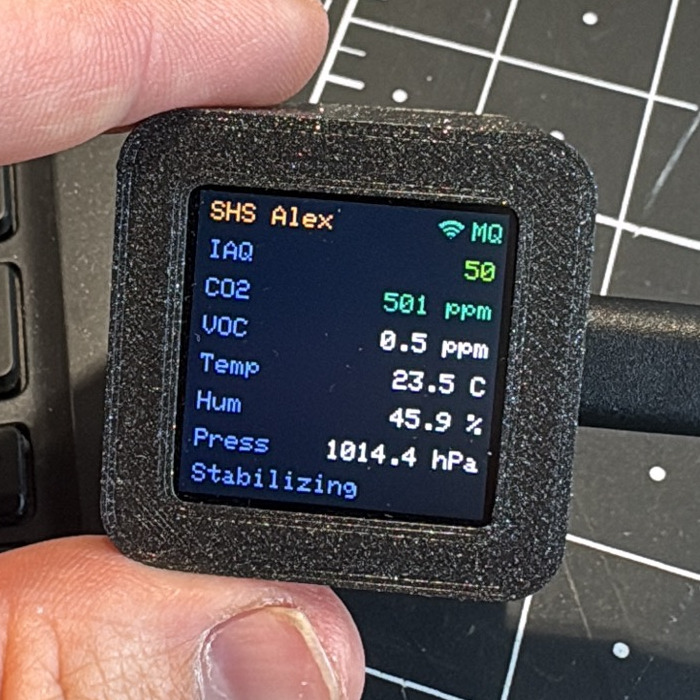
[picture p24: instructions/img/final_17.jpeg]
Finished device showing live sensor readings, IAQ still stabilizing after first boot


</div>

---

## 8. Troubleshooting

| Symptom | What to check |
|---|---|
| Display says **BME68x err** | Wiring: 3V3 not 5V, SDA→GPIO 3, SCL→GPIO 2. Reseat the connectors and press RESET. |
| Never leaves **Setup mode** | Wrong Wi-Fi password, or a 5 GHz-only network. The ESP32-C6 is 2.4 GHz only. |
| Test says **✗ 403** | The device ID is already claimed with a different write key, which happens if this board previously ran another image. Tell your instructor: the ID needs freeing, or it frees itself 48 h after that device's last reading. |
| Test says **✗ could not reach…** | The device is on Wi-Fi but has no internet. Captive-portal networks (hotel/campus guest Wi-Fi) will not work. |
| Nothing on the dashboard | If you pressed **Send a test reading**, your data is already there: open [diy-sensor.org/dashboard](https://diy-sensor.org/dashboard) and look for your device by name, or check the device ID in the direct URL. If you did not, the next scheduled reading is up to 5 minutes away. |
| **IAQ accuracy fell from 3 back to 1** | Normal. BSEC is rebuilding its baseline after a change in the air, a restart, or air that never varies. It climbs back on its own. |
| **I need to change a setting** | Press **RESET twice quickly**. The display tells you when the window is open, then setup mode returns. In the current enclosure the button is covered. Either take the board out or power it up where its saved network is unreachable to open setup mode. |

The setup portal also offers three separate resets: *Forget Wi-Fi network*, *Clear IAQ calibration*, and *Factory reset* (settings + Wi-Fi). Only **Clear IAQ calibration** discards the air-quality calibration, which takes hours to rebuild. **Factory reset** also removes any custom device ID and restores the ID derived from the board.

---

## Taking it further

The device keeps publishing wherever it finds a Wi-Fi network it knows. Press RESET twice to enter your home Wi-Fi details in setup.

If a workshop image was used, note that it is tied to that event and comes off the flasher page afterwards. Removing the image from the flasher does not change the firmware on your board. It can keep publishing while the workshop API key remains active. You can read its write key from the setup page by pressing RESET twice.

On diy-sensor.org, your readings last exactly as long as your device keeps sending them. A device that stops publishing is removed 48 hours later, together with its history, and its device ID becomes free for anyone to claim again. The dashboard is public throughout, so treat nothing on it as private or as a backup.

Three options from here:

- **Keep using the dashboard**: reflash with the **diy-sensor.org** image, which needs no key and stays on the flasher page. Same device ID, same dashboard. If you do it before a workshop device has expired, copy the write key from the old setup page first and paste it into the new build's *Write key* field, and the device carries on uninterrupted.
- **Move it to Home Assistant**: flash the **Home Assistant** image and point it at your own broker. [`build_instructions_extended.md`](build_instructions_extended.md) walks through the broker side.
- **Build the firmware yourself**: [`build_instructions_extended.md`](build_instructions_extended.md) sets up the Arduino toolchain so you can change the code, the display, or the pins.

For background on how the sensors work and why the design choices were made, see [`background_information.md`](background_information.md).

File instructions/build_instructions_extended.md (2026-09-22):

# Extended Build Instructions — Building the Firmware from Source

This guide covers the Arduino path: setting up the toolchain, building the firmware from source, and connecting the device to **Home Assistant** over MQTT. It is the long way round, and it is what to read if you want to change the code rather than just run it.

**Do the hardware first.** Wiring, the pre-enclosure sensor test, and enclosure assembly are in [`build_instructions.md`](build_instructions.md) — §1–4 — and are not repeated here. If all you want is a working sensor, that guide alone is enough: it flashes a prebuilt image from the browser and takes about 90 minutes.

Two firmware paths are covered here:

- **Arduino + MQTT** (§1–3): the full firmware, the colour display UI, and Home Assistant over MQTT.
- **ESPHome** (§4): no Arduino IDE and no broker, but a minimal display and not verified on hardware.

**Using diy-sensor.org instead of Home Assistant?** If you missed the dashboard QR code or don’t know your device ID, you can always open [diy-sensor.org/dashboard](https://diy-sensor.org/dashboard). Look for the device name you chose during setup and select it to open its readings.

The device is **always on** (USB powered): the live display and the BME680’s multi-day air-quality self-calibration mean it never goes to sleep.

---

## 1. Flash the Arduino Firmware

### 1.1 Install Arduino IDE and the ESP32 Board Package

1. Download and install the [Arduino IDE](https://www.arduino.cc/en/software).
2. Open **File ▸ Preferences** and add this URL to *Additional Boards Manager URLs*: `https://espressif.github.io/arduino-esp32/package_esp32_index.json`
3. Open **Tools ▸ Board ▸ Boards Manager**, search for `esp32`, and install **esp32 by Espressif Systems**.
4. Select **Tools ▸ Board ▸ ESP32 Arduino ▸ ESP32-C6 Dev Module**.
5. Set **Tools ▸ USB CDC On Boot ▸ Enable**. The ESP32-C6 uses native USB — without this the Serial Monitor won't receive output during boot and the port may not appear reliably.
6. Set **Tools ▸ Partition Scheme ▸ Huge APP (3MB No OTA/1MB SPIFFS)**. The BSEC2 library is large and the default scheme is too small.

### 1.2 Install Required Libraries

In **Tools ▸ Manage Libraries**, search for and install:

| Library | Author |
|---|---|
| GFX Library for Arduino | Moon On Our Nation |
| BSEC2 Software Library | Bosch Sensortec |
| BME68x Sensor library | Bosch Sensortec |
| WiFiManager | tzapu |
| PubSubClient | Nick O'Leary |

> **Do not install the Arduino "QRCode" library (ricmoo).** The ESP32 core already ships Espressif’s QR encoder, which the firmware uses for the dashboard QR code shown after setup. Both headers are called `qrcode.h`, and the library shadows the core one, so installing it breaks the build with an `esp_qrcode_handle_t` was not declared`.

### 1.3 Add the ESP32-C6 BSEC Blob (important!)

Bosch's `BSEC2` library ships precompiled algorithm blobs for several chips but, as of v1.10.x, **not for the ESP32-C6**. The C6 is soft-float RISC-V (`rv32imac`) and is ABI-compatible with the ESP32-C3 blob, so you create the C6 folder as a copy of the C3 one.

Find your Arduino libraries folder for your OS, then run the commands below.

> The folder is called `bsec2` here. Depending on how the library was installed it may instead be named `BSEC2_Software_Library`; use whichever exists. If neither does, search your libraries folder for the directory containing `esp32c3/libalgobsec.a`.

**Linux** — `~/Arduino/libraries/`
```bash
cd ~/Arduino/libraries/bsec2/src
mkdir -p esp32c6
cp esp32c3/libalgobsec.a esp32c6/libalgobsec.a
```

**macOS** — `~/Documents/Arduino/libraries/`
```bash
cd ~/Documents/Arduino/libraries/bsec2/src
mkdir -p esp32c6
cp esp32c3/libalgobsec.a esp32c6/libalgobsec.a
```

**Windows** — open `%USERPROFILE%\Documents\Arduino\libraries\bsec2\src\` in File Explorer, create a folder named `esp32c6`, and copy `libalgobsec.a` from `esp32c3\` into it.

> If you ever get a *linker error* about `libalgobsec` after updating the library, the update removed the `esp32c6/` folder — just re-run the copy above.

### 1.4 Pick the Build Variant

**There is nothing to configure before uploading.** Device name, broker address, MQTT credentials, publish interval and temperature offset are *not* compiled in: the firmware stores them in the chip's flash and you enter them in a setup page the device serves over its own Wi-Fi access point (⚙1.6). That is deliberate — it means one build works on every board, which is what makes the [web flasher](../web-flasher/) possible.

The one compile-time choice is *which backend this image talks to*. Open `code/shs_modular/shs_modular.ino` in the Arduino IDE (it opens all the `.ino` modules as tabs), switch to the **`config.h`** tab, and set:

```c
#define SHS_VARIANT  SHS_VARIANT_MQTT_HA      // Home Assistant over MQTT
// #define SHS_VARIANT  SHS_VARIANT_SENSORBOARD  // diy-sensor.org over HTTPS
// #define SHS_VARIANT  SHS_VARIANT_DISPLAY      // display + serial only, no networking
```

Leave it at `SHS_VARIANT_MQTT_HA` for this guide.

The other values in `config.h` are the pin map and the *factory defaults* — what a device starts with on its very first boot, or after a factory reset. Change them only if you are producing many devices and want a different starting point.

### 1.5 Upload

1. Connect the board via USB-C.
2. Select the port: **Tools ▸ Port**.
3. Click **Upload**.

> **Upload fails / port busy?** Put the board in download mode: 1. Unplug the board. 2. Hold the **BOOT** button. 3. Plug back in while holding BOOT. 4. Release after ~2 seconds, then retry Upload.

### 1.6 Set Up the Device

On first boot — and whenever it cannot reach a saved network — the device opens a setup portal. The display shows you what to join and where to go.

1. The device starts an access point with a friendly name such as **`SHS-Bouncy-Alpaca`** (no password). Join the exact network name shown on its display.
2. Join it from a phone or laptop. The setup page usually opens by itself; if not, browse to **`192.168.4.1`**.
3. **Configure WiFi** — pick your network and enter the password.
4. **Setup** — enter your device name and the MQTT settings from §3:

   | Field | Value |
   |---|---|
   | Device name | Whatever you want it called in Home Assistant |
   | MQTT broker host | Your broker’s IP or hostname, e.g. `192.168.1.10` |
   | MQTT port | `1883` (or `8883` with TLS) |
   | MQTT username / password | The broker account you created |
   | Mode | `0` = HA auto-discovery (leave this) |
   | Publish interval | **Minutes** between readings; `5` is the default |
   | Temperature offset | °C to subtract for self-heating; see §3 |
   | Display rotation | 0→3 quarter turns, for however the enclosure sits |

   The portal also shows **Topic prefix**, **HA discovery prefix** and **Use TLS**. Leave all three alone unless you know you need them: the defaults are what the Home Assistant MQTT integration expects.

5. **Live readings & connection test** — check the sensor values look sane, then press **Send a test reading** to confirm the broker accepts the connection *before* you walk away from the device.
6. **Finish setup**.

The portal closes on its own after 10 minutes if you don't.

> **Getting back in later.** Press **RESET twice in quick succession** — the display tells you when the window is open. This is how you can change the broker address, move the device to a new network, or recalibrate, without reflashing.
>
> The current enclosure covers the RESET button, so reaching it means taking the board out. Without touching it: the device opens setup mode on its own at power-up whenever the saved network is unreachable — powering it up away from that network (or with it switched off) is the button-free way back in. Losing the network while running does not reopen the portal; it reconnects in the background.
>
> **The device ID** shown on the display and the setup page is derived from the chip and never changes, even across a reflash or a factory reset. It is what keys the MQTT topics and the Home Assistant entities, so re-flashing a board does not orphan its history.

---

## 2. Connect to Home Assistant (MQTT)

The Arduino firmware uses **MQTT discovery**: it announces its own entities to Home Assistant, so there is nothing to configure by hand in HA.

1. In Home Assistant, install the **Mosquitto broker** add-on (*Settings ▸ Add-ons ▸ Add-on Store*) and start it.
2. Add the **MQTT integration** if it isn't already set up (*Settings ▸ Devices & Services ▸ Add Integration ▸ MQTT*).
3. Create an MQTT user for the device (e.g. in the Mosquitto add-on config or a HA user). You enter these in the setup portal (§1.6) — no re-upload needed.
4. Power the device. Within a few seconds it connects and a new device with the name you gave it appears under *Settings ▸ Devices & Services ▸ MQTT*, with entities: IAQ, IAQ Accuracy, CO₂ equivalent, Breath VOC equivalent, Temperature, Humidity, Pressure.

Readings are published at the interval set in the portal — **5 minutes** by default. The display still refreshes every ~3 s; the interval only controls reporting.

> **Don't see it?** Open the **Serial Monitor** at **115200 baud** and watch for `MQTT connecting...connected` and `MQTT discovery configs published`. If it says `failed (rc=...)`, the broker host or credentials are wrong, or the MQTT user lacks publish rights — press RESET twice and correct them in the portal.

### What the three MQTT modes do

The portal's **Mode** field decides how readings reach the broker. Leave it at `0` unless you have a reason not to.

| Mode | Publishes | Use when |
|---|---|---|
| `0` — discovery | Retained config per metric under `homeassistant/sensor/…`, readings as one JSON message to `<prefix>/<id>/state` | Home Assistant. Entities appear by themselves. |
| `1` — flat | One plain topic per metric, `<prefix>/<id>/temperature` and so on | Node-RED, Grafana, or your own subscriber |
| `2` — both | Flat topics, plus discovery configs pointing at them | You want both, e.g. HA *and* a script |

An LWT on `<prefix>/<id>/status` marks the device unavailable if it drops off the network, so Home Assistant shows it as offline rather than showing a stale last value forever.

---

## 3. Understand the Air-Quality Readings

The BME680's gas sensor needs to **self-calibrate** before IAQ is trustworthy. The footer on the display (and the *IAQ Accuracy* entity in HA) reports progress:

| Accuracy | Meaning |
|---|---|
| 0 | Stabilizing — gas heater warming up; ignore IAQ |
| 1–2 | Calibrating — collecting its baseline (can take hours) |
| 3 | Calibrated — IAQ is now reliable |

Reaching accuracy 3 the first time can take a few hours of varied air; full calibration uses a 4-day window. The firmware saves the calibrated state to flash and restores it on boot, so it doesn't start from scratch every time. See [`background_information.md`](background_information.md) for what IAQ, CO₂-equivalent, and VOC actually mean.

Finished device showing live sensor readings — IAQ still stabilizing after first boot

---

## 4. Alternative — ESPHome

> ⚠️ **This path has not been tested on real hardware.** The YAML is provided as a starting point; pin assignments, `bme680_bsec2` platform support, and the ST7789 display block have not been verified against a physical board. Use it at your own risk and expect some trial and error.

Prefer ESPHome? It needs no Arduino IDE and no MQTT broker — Home Assistant discovers the device over ESPHome's native API.

1. In Home Assistant, install the **ESPHome** add-on and open its dashboard.
2. In the add-on's config directory, add `code/esphome/smart_home_sensor.yaml` (copy its contents into a new device, or drop the file in).
3. Create a `secrets.yaml` with `wifi_ssid`, `wifi_password`, and `ap_password`.
4. **Install** to the board (USB the first time, then over-the-air after).
5. Home Assistant auto-discovers the device — accept it under *Settings ▸ Devices & Services*.

> **Note:** the ESPHome variant exposes the same sensor entities but only a **minimal** display layout — the rich colour-coded UI exists only in the Arduino build. See the comments at the top of the YAML.

---

## 5. Troubleshooting

Open the **Serial Monitor** at **115200 baud** to see what the device is doing.

**Sensor not found (`BME68x err ...` on the display):**
- Re-check the four wires ([`build_instructions.md`](build_instructions.md) §2). Swapped SDA/SCL is the usual cause.
- Some modules sit at I2C address `0x77` instead of `0x76`; the firmware probes both, so a wrong address is rarely the problem — a wiring fault is more likely.

**I2C scan sketch.** To confirm the board sees the sensor at all, upload this minimal sketch and watch the Serial Monitor:

```cpp
#include <Wire.h>
void setup() {
  Serial.begin(115200);
  delay(500);
  Wire.begin(3, 2);    // SDA=GPIO3, SCL=GPIO2
  Serial.println("Scanning I2C...");
  for (byte a = 1; a < 127; a++) {
    Wire.beginTransmission(a);
    if (Wire.endTransmission() == 0) Serial.printf("  device at 0x%02X\n", a);
  }
}
void loop() {}
```

Expect a device at `0x76` (or `0x77`). Nothing found = a wiring/power problem.

**IAQ stuck at "Stabilizing" / accuracy 0:** normal for the first minutes-to-hours. The gas sensor calibrates against changing air — open a window, breathe near it, then ventilate.

**MQTT won't connect:** press RESET twice to reopen the setup portal and check the broker host, port and credentials; confirm the Mosquitto add-on is running and that the MQTT user may publish. The portal's **Send a test reading** button reports the failure directly.

**Wrong settings and no way in:** press RESET twice within about three seconds — the display shows the window. The portal offers three separate resets: *Forget Wi-Fi network*, *Clear IAQ calibration*, and *Factory reset* (settings + Wi-Fi). None of them changes the device ID, and only the middle one discards the air-quality calibration — which takes hours to rebuild, so it is deliberately not bundled into the others.

**Linker error mentioning `libalgobsec`:** the BSEC2 ESP32-C6 blob is missing — redo §1.3.

**Upload fails:** use the BOOT-button download-mode recovery in §1.5.

---

## What's Next?

Your sensor now streams temperature, humidity, pressure, and air-quality data into Home Assistant. Try building an automation — for example, send a phone notification when *CO₂ equivalent* rises above 1000 ppm ("time to open a window"), or chart IAQ over a week to see how cooking and ventilation affect your air.

For background on how the sensors work and why the design choices were made, see [`background_information.md`](background_information.md).

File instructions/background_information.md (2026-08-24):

# Background Information

Useful context for understanding *why* this device is built the way it is.

## Sensor Choice

### Environmental & Air-Quality Sensors

#### Overview

| Sensor | Measures | Interface | Advantages | Limitations |
|---|---|---|---|---|
| DHT11 / DHT22 | Temperature, humidity | 1-Wire | Cheap, very common in tutorials | Slow (1 reading/s), low accuracy |
| BME280 | Temperature, humidity, pressure | I2C / SPI | All-in-one, accurate, low power | No gas / air-quality sensing |
| **BME680** | **Temp, humidity, pressure, gas (VOC)** | **I2C / SPI** | **Adds a gas sensor → air-quality index via BSEC** | **Gas sensor needs multi-day self-calibration; self-heats** |
| SCD40 / SCD41 | **True** CO₂ (NDIR), temp, humidity | I2C | Measures real CO₂ concentration | More expensive, larger, higher power |

#### Background

Temperature and humidity sensors appear in countless IoT projects; the main trade-offs are
accuracy, speed, and *what* they measure. The BME280 is a popular all-in-one for temperature,
humidity, and pressure. The **BME680** adds a fourth element: a small heated metal-oxide (MOX)
**gas sensor** whose resistance changes in the presence of volatile organic compounds (VOCs) —
the gases given off by people, cooking, cleaning products, furniture, and so on.

That extra channel is what lets the BME680 estimate **air quality**, not just comfort. It does
*not* measure true CO₂ — for that you'd need an NDIR sensor like the SCD40 — but for a learning
project it packs the most interesting physics into one cheap, well-supported chip.

#### Workshop Sensor Choice

We use the **Bosch BME680** with Bosch's **BSEC2** software library. The raw MOX gas resistance
on its own is hard to interpret, so Bosch ships BSEC2: a closed-source algorithm that fuses the
gas, temperature, and humidity signals over time and outputs human-meaningful values. It
communicates over I2C (address `0x76`, sometimes `0x77`).

---

## What the Air-Quality Numbers Mean

BSEC2 turns the raw sensor signals into several **virtual sensors**:

- **IAQ (Indoor Air Quality index)** — a unitless score where lower is cleaner air. Bosch's
  scale runs from 0 (excellent) to 500 (extremely polluted). The firmware colour-codes it:

  | IAQ | Meaning |
  |-----|---------|
  | 0–50 | Good |
  | 51–100 | Moderate |
  | 101–150 | Lightly polluted |
  | 151–200 | Moderately polluted |
  | 201–300 | Heavily polluted |
  | 300+ | Severely polluted |

- **CO₂-equivalent (ppm)** — an *estimate* of CO₂ derived from VOC trends, scaled to look like
  a CO₂ reading (outdoor air ≈ 400 ppm; ~1000 ppm is the common "ventilate" threshold). It is
  **not** a true CO₂ measurement, but it tracks the same thing in occupied indoor spaces
  (people exhale both CO₂ and VOCs).

- **Breath-VOC-equivalent (ppm)** — an estimate of the concentration of exhaled VOCs.

### Why calibration takes days

A MOX gas sensor has no absolute zero — it only senses *changes* in gas resistance, and that
baseline drifts with the sensor and its environment. BSEC continuously learns the baseline from
the cleanest air it has recently seen. It reports an **accuracy** level (0–3); IAQ is only
trustworthy at level 3. Reaching it needs exposure to a *range* of air over time — Bosch's
tuning here uses a **4-day** calibration window. The firmware saves the learned state to the
ESP32's flash (NVS) and restores it on boot, so the device doesn't relearn from scratch every
power-cycle.

### Why accuracy falls back to 2 or 1

The accuracy figure is not a score for the reading; it is BSEC's confidence in *its own
baseline*. The BME680 does not measure VOCs absolutely. It measures a gas resistance that
drifts with the sensor's age, its temperature, the humidity, and whatever it has been
breathing, so BSEC continuously estimates what clean air looks like *for this sensor, right
now* and expresses everything relative to that estimate.

A drop from 3 to 2 to 1 therefore means the baseline no longer explains what the sensor is
seeing, so BSEC has discarded part of it and is rebuilding. **It is a recalibration, not a
regression**, and it is expected behaviour rather than a fault. Four things commonly cause it:

- **The air or the location genuinely changed** — the device moved rooms, a window stood
  open for hours, the heating season started.
- **Too little variation.** The algorithm anchors itself on periodically seeing relatively
  clean air. A sensor in constantly stuffy air, or in air that never changes at all, slowly
  loses its reference and confidence decays.
- **Humidity swings.** Gas resistance depends strongly on humidity. BSEC compensates, but a
  large or fast swing widens its uncertainty.
- **Restarts.** The calibrated state is written to NVS only once accuracy reaches 3, and
  then at most every six hours (`STATE_SAVE_PERIOD_MS`). Reboot a few hours after the last
  save and BSEC resumes from a slightly stale baseline, which it may then downgrade. A run
  of reflashes and double-resets during setup is a common explanation.

Occasional dips that recover to 3 within a few hours are normal. A device that keeps sagging
to 1 for days in a stable room is worth investigating, and the **temperature offset** is the
first suspect: humidity is derived from temperature and feeds the gas compensation, so an
offset that is wrong by several degrees destabilises the baseline with a device-shaped error
rather than a real one.

In practice: trust IAQ at 3, treat it as indicative at 2, and at 0–1 ignore the absolute
value while still watching which way it moves.

### Self-heating and the temperature offset

The ESP32 and the LCD backlight produce heat, which warms the BME680 above true room
temperature. BSEC subtracts a fixed **temperature offset** to compensate (the *Temperature offset*
field in the setup portal, `DEFAULT_TEMP_OFFSET_C` in `config.h` for the value a
freshly flashed device starts with, `temperature_offset` in the ESPHome YAML). To calibrate it: let the device run
20–30 minutes until the reported temperature plateaus, compare it to a real thermometer, and
**add** what is left over to the offset already in use —

```text
new offset = current offset + (reported − real thermometer)
```

Setting the offset *to* the difference is the easy mistake, and it undoes the correction
you are measuring: a device shipping with a 5 °C offset that still reads 2.5 °C high needs
7.5 °C, not 2.5 °C. The humidity reading is derived from temperature, so fixing
the offset improves humidity too. This is also why an enclosure should give the sensor some
airflow and keep it away from the warm side of the board.

---

## How the System Works

### The Firmware

Unlike a battery sensor that sleeps between readings, this device is **always on** — it needs
to keep the gas sensor heated for BSEC to calibrate, and the display is meant to be glanceable.
The loop is simple:

1. **Read** — BSEC samples the BME680 every ~3 seconds (low-power mode) and produces the
   virtual outputs (IAQ, CO₂-eq, VOC, temperature, humidity, pressure).
2. **Display** — the latest values are drawn on the ST7789 screen, colour-coded by air quality.
3. **Publish** — at most every 30 seconds the readings are sent to Home Assistant.

The code lives in `code/shs_modular/`. `shs_modular.ino` ties the modules together; everything
you configure is entered in the device's own setup portal — nothing is compiled in.

### Getting Data into Home Assistant — Two Paths

A DIY device can talk to Home Assistant several ways. This project demonstrates the two most
common, and you pick one when you choose a firmware.

#### Path A — MQTT auto-discovery (the Arduino build)

**MQTT** is a lightweight publish/subscribe messaging protocol used widely in IoT. A central
**broker** (here, the Mosquitto add-on running inside Home Assistant) relays messages between
devices and HA.

Home Assistant supports **MQTT discovery**: if a device publishes a small *config* message to a
special topic, HA automatically creates the matching entity — no manual YAML in HA. On connect,
our firmware publishes one retained config message per metric to
`homeassistant/sensor/<DEVICE_ID>/<metric>/config`, then sends readings as a single JSON
message to its state topic:

```json
{
  "iaq_accuracy": 3,
  "iaq": 42,
  "co2": 612,
  "voc": 0.83,
  "temperature": 21.4,
  "humidity": 47.2,
  "pressure": 1013.6
}
```

It also uses an MQTT **Last Will and Testament**: if the device drops off the network, the
broker automatically marks it *offline* in HA.

```
[BME680] --I2C--> [ESP32-C6 firmware] --MQTT--> [Mosquitto broker] --> [Home Assistant]
```

This path keeps the full custom firmware (and the colour display), and teaches a protocol you'll
meet everywhere in IoT. It's also broker-portable — the same device works with any MQTT
broker, not just Home Assistant.

#### Path B — ESPHome native API (the ESPHome build)

[ESPHome](https://esphome.io/) is a system that builds ESP firmware from a YAML description.
Instead of MQTT it uses its **native API**, a direct, encrypted connection that Home Assistant
discovers and adopts automatically — no broker required. Our `bme680_bsec2` config exposes the
same metrics in a few lines of YAML.

```
[BME680] --I2C--> [ESP32-C6 / ESPHome] --native API--> [Home Assistant]
```

This is the simplest path and the most idiomatic for Home Assistant, at the cost of writing no
real firmware (so you learn less about what's happening) and only a minimal display.

#### Which to use?

| | MQTT (Arduino) | ESPHome |
|--|---|---|
| Extra infrastructure | Needs an MQTT broker | None |
| Custom display UI | Full colour-coded UI | Minimal |
| What you learn | Firmware + a core IoT protocol | YAML configuration |
| Portability | Any MQTT broker / platform | Home Assistant ecosystem |
| Effort | More setup | Least setup |

The workshop uses the **MQTT/Arduino** build as the main path because it teaches more; ESPHome
is offered as a fast, low-friction alternative.

---

## Similar Projects

### Airrohr / sensor.community
A European citizen-science project for DIY outdoor particulate-matter (PM2.5/PM10) sensors,
originally from Stuttgart (luftdaten.info). Uses an ESP8266 + SDS011 laser dust sensor and
uploads readings to a public map. A good reference for how a grassroots network of DIY sensors
can produce city-scale air-quality data.
https://sensor.community/en/sensors/airrohr/

### ESPHome BME680 via BSEC
The official ESPHome component used by the alternative build — documents every option the
`bme680_bsec2` platform exposes.
https://esphome.io/components/sensor/bme680_bsec2.html

### Bosch BSEC2 / BME68x
Bosch Sensortec's documentation for the gas sensor and the BSEC fusion algorithm — the source
of the IAQ / CO₂-equivalent / VOC outputs.
https://www.bosch-sensortec.com/software-tools/software/bme688-software/

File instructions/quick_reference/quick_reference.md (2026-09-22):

# Smart Home Sensor: Quick Reference

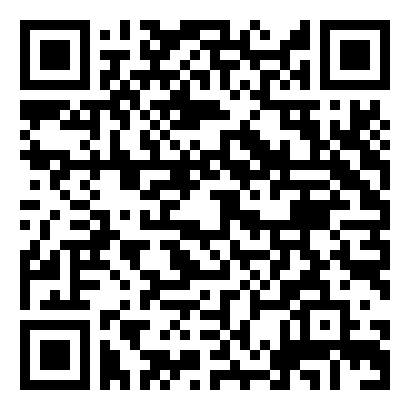
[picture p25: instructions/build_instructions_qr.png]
QR code linking to the full build instructions


You build a small indoor air-quality and room-climate sensor: air quality, temperature, humidity and pressure on a little display. The sensor can also send its readings to an online dashboard or your own smart-home system (MQTT/Home Assistant compatible).

**Build instructions with pictures:** scan the QR code

## 1. Solder and wire the BME680

Thread the stripped ends through the pad holes **from the plain back**, bend them flat against the labelled front and solder there. Then wire the sensor to the board as shown.

Six-pin microcontroller connector to BME680: 3V3 to VCC, GND to GND, GPIO3 to SDA, GPIO2 to SCL. Leave 5V and GPIO1 unused.

> Swapped SDA/SCL and wrong board pins are the most common no-sensor causes.

## 2. Flash and test before assembly

**Web flasher:** `https://alexanderkutschera.com/smart_home_sensor`

1. Keep the sensor **outside the enclosure**; plug the board in.
2. Web flasher → select the **workshop image** → **Connect**.
3. Pick the port `USB JTAG/serial debug unit` → **Install**.
4. After the reboot, wait for green **OK** under **BME680 sensor** on the display.

## 3. Assemble the enclosure

- **Main housing** (bottom)
- **Board**: display to the open front
- **Lower inlay**: fixes board
- **Upper inlay**: BME680 in the recess, **component side up** towards the lid grille
- **Lid** (top)
- **Insulation** between board and sensor, e.g. the board's styrofoam

> **The lid goes on at an angle**, not straight down: slide its **long tab** into the rails, then lower the other edge until the **short tab** snaps in.

## 4. Set up on the device

1. First boot opens a Wi-Fi network named like **`SHS-Bouncy-Alpaca`** (no password) — use the exact name on the display.
2. Browse to **`192.168.4.1`** → **Configure WiFi** (2.4 GHz only).
3. **Setup:** give the device a name.
4. *Live readings & connection test* → **Send a test reading**. Green **✓ 201** or **200** means stored.
5. **Finish.**

> **Back into setup later: press RESET twice quickly.** The current enclosure covers that button → slide the board out, or power up away from the saved Wi-Fi: with no known network it opens setup itself.

## 5. Your readings

The QR code on the display links straight to your readings. Missed it, or don't know your ID? Go to **diy-sensor.org/dashboard**, find the name you gave your device during setup and select it. New readings arrive every **5 minutes**; the display refreshes every few seconds.

## 6. Air quality

- **IAQ accuracy 0** stabilizing
- **1–2** calibrating (takes hours)
- **3** trusted — a drop back to 1 is normal, BSEC is rebuilding its baseline
- **IAQ 0–50** good · **51–100** moderate
- **101–150** light · **151–200** moderate
- **201–300** heavy · **300+** severe pollution

> **Temperature reads high**: the board warms the sensor. After 20–30 min, *add* the remaining error to the offset in the setup page: `new = current + (reported − real)`. It starts at 5 °C, not 0.

## 7. Troubleshooting

- **No port in the flasher?** Use a USB-C **data** cable. Still nothing: unplug, hold **BOOT**, plug in, release after ~2 s.
- **BME680 NOT FOUND:** power off and re-check the four wires — 3V3 (not 5V), GND, SDA → GPIO3, SCL → GPIO2 — and the solder joints.
- **No setup Wi-Fi:** look for the exact name on the display; 2.4 GHz only.
- **Test reading fails:** check the Wi-Fi password and internet access.
- **Nothing on the dashboard yet:** the first reading takes up to 5 min.

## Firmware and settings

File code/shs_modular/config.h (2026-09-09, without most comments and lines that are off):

#pragma once
#include <Arduino.h>
#define SHS_VARIANT_MQTT_HA      1   // Home Assistant via MQTT (broker required)
#define SHS_VARIANT_SENSORBOARD  2   // diy-sensor.org over HTTPS (short workshop)
#define SHS_VARIANT_DISPLAY      3   // Display + serial only, no networking
#define SHS_VARIANT  SHS_VARIANT_MQTT_HA
#if   SHS_VARIANT == SHS_VARIANT_MQTT_HA
  #define USE_MQTT         1
  #define USE_SENSORBOARD  0
#elif SHS_VARIANT == SHS_VARIANT_SENSORBOARD
  #define USE_MQTT         0
  #define USE_SENSORBOARD  1
#elif SHS_VARIANT == SHS_VARIANT_DISPLAY
  #define USE_MQTT         0
  #define USE_SENSORBOARD  0
#else
  #error "Unknown SHS_VARIANT — see the list above"
#endif
#define USE_NETWORK  (USE_MQTT || USE_SENSORBOARD)
#define USE_DISPLAY  1   // ST7789 240x240 LCD on the Waveshare board
#define DEFAULT_DEVICE_NAME       "SHS"    // keep short — the title area fits ~14 chars
#define DEFAULT_DEVICE_ID_PREFIX  "shs"    // [a-z0-9-] only; the API rejects anything else
#define SHS_DEVICE_ID_MIN_LEN     3        // shorter than this is a typo, not an ID
#define DEFAULT_API_URL       "https://diy-sensor.org/sensor/measurement"
#define DASHBOARD_URL_PREFIX  "diy-sensor.org/dashboard/device/"
#define DASHBOARD_URL_FULL    "https://diy-sensor.org/dashboard/device/"
#if USE_SENSORBOARD && __has_include("workshop_secrets.h") && !defined(SHS_NO_WORKSHOP_SECRETS)
  #include "workshop_secrets.h"
#endif
  #define WORKSHOP_API_KEY  ""
  #define SHS_HAS_WORKSHOP_KEY  0
  #define WORKSHOP_PROJECT  ""
  #define WORKSHOP_KEY_SALT ""       // no salt: random write key on first boot
  #define SHS_DERIVED_WRITE_KEY  0
#define DEFAULT_API_KEY  WORKSHOP_API_KEY
#define DEFAULT_PROJECT  WORKSHOP_PROJECT
#define DEFAULT_MQTT_HOST      ""              // set in the portal
#define DEFAULT_MQTT_PORT      1883
#define DEFAULT_MQTT_USER      ""
#define DEFAULT_MQTT_PASS      ""
#define DEFAULT_MQTT_TLS       false
#define DEFAULT_MQTT_PREFIX    "smart_home_sensor"   // <prefix>/<id>/state, .../status
#define DEFAULT_HA_DISC_PREFIX "homeassistant"       // HA's discovery topic root
#define MQTT_MODE_DISCOVERY  0
#define MQTT_MODE_FLAT       1
#define MQTT_MODE_BOTH       2
#define DEFAULT_MQTT_MODE    MQTT_MODE_DISCOVERY
#define DEFAULT_PUBLISH_INTERVAL_MIN  5
#define MIN_PUBLISH_INTERVAL_MIN      1
#define MAX_PUBLISH_INTERVAL_MIN      1440   // a day; beyond this it is a typo
#define DEFAULT_TEMP_OFFSET_C  5.0f
#define STATE_SAVE_PERIOD_MS   (6UL * 60UL * 60UL * 1000UL)  // 6 hours
#define DEFAULT_LCD_ROTATION  1
#define PIN_MISO     5
#define PIN_MOSI     6
#define PIN_SCLK     7
#define PIN_LCD_CS   14
#define PIN_LCD_DC   15
#define PIN_LCD_RST  21
#define PIN_BL       22
#define PIN_BME_SCL  2
#define PIN_BME_SDA  3
#define SHS_RGB565(r, g, b) \
  ((uint16_t)((((r) & 0xF8) << 8) | (((g) & 0xFC) << 3) | ((b) >> 3)))
#define COLOR_INFO  SHS_RGB565(0x9F, 0xB6, 0xCD)   // gray-blue
#define COLOR_OK    SHS_RGB565(0x06, 0xD6, 0xA0)   // green
#define COLOR_WARN  SHS_RGB565(0xFF, 0xD1, 0x66)   // amber
#define COLOR_ERR   SHS_RGB565(0xEF, 0x47, 0x6F)   // red
#define SHS_PROJECT_LEN    48
#define SHS_WRITE_KEY_LEN  40   // 32 hex chars + NUL
#define SHS_API_URL_LEN   128
#define SHS_API_KEY_LEN    96   // generous: keys are operator-chosen strings
static_assert(sizeof(DEFAULT_API_KEY) <= SHS_API_KEY_LEN,
              "WORKSHOP_API_KEY does not fit in Settings::apiKey — raise SHS_API_KEY_LEN");
static_assert(sizeof(DEFAULT_PROJECT) <= SHS_PROJECT_LEN,
              "WORKSHOP_PROJECT does not fit in Settings::project — raise SHS_PROJECT_LEN");
static_assert(sizeof(DEFAULT_API_URL) <= SHS_API_URL_LEN,
              "DEFAULT_API_URL does not fit in Settings::apiUrl — raise SHS_API_URL_LEN");
struct Settings {
  char     deviceName[32];
  char     deviceId[32];          // derived from the MAC (or overridden below)
  char     deviceIdOverride[32];  // empty = use the derived ID; set in the portal
  char     project[SHS_PROJECT_LEN];
  char     writeKey[SHS_WRITE_KEY_LEN];
  char     apiUrl[SHS_API_URL_LEN];
  char     apiKey[SHS_API_KEY_LEN];
  char     mqttHost[64];
  char     mqttUser[32];
  char     mqttPass[64];
  char     mqttPrefix[32];
  char     haDiscPrefix[32];
  uint16_t mqttPort;
  uint8_t  mqttMode;              // MQTT_MODE_*
  bool     mqttTls;
  uint32_t publishIntervalMin;
  uint8_t  lcdRotation;           // 0-3, quarter turns
  float    tempOffsetC;
};
extern Settings settings;
void loadSettings();               // populate `settings` from NVS (or defaults on first boot)
void saveSettings();               // persist `settings` to NVS
void resetSettingsToDefaults();    // DEFAULT_* into RAM; call saveSettings() to persist
void clearWiFiCredentials();       // forget the saved network only
void clearBsecState();             // discard the IAQ calibration only
bool setDeviceIdOverride(const char *raw);  // "" clears it; false = rejected as invalid
struct SensorPacket {
  float   iaq          = NAN;
  uint8_t iaqAccuracy  = 0;     // 0=stabilizing .. 3=fully calibrated
  float   co2          = NAN;   // ppm  (CO2-equivalent)
  float   voc          = NAN;   // ppm  (breath-VOC-equivalent)
  float   temperature  = NAN;   // °C   (heat-compensated)
  float   humidity     = NAN;   // %    (heat-compensated)
  float   pressure     = NAN;   // hPa
};
SensorPacket sensorLatest();               // bme680.ino — most recent reading
bool         bme680Ok();                   // bme680.ino — sensor found and subscribed
void         displayUpdate(const SensorPacket &p);
void         displayPortalSensor(const char *msg, uint16_t color);
void         displayQr(const char *url, uint32_t showMs);
void         mqttPublish(const SensorPacket &p);
int          sensorboardSend(const SensorPacket &p);  // HTTP code, -1 if offline
bool         isValidFloat(float v);

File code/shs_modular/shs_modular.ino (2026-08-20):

// ============================================================================
//  Smart Home Sensor — modular firmware (entry point)
//
//  Waveshare ESP32-C6-LCD-1.3 + BME680 (Bosch BSEC2). An always-on,
//  USB-powered device: the live display and BSEC's multi-day IAQ
//  self-calibration mean it never deep-sleeps.
//
//  One source tree, three builds — pick with SHS_VARIANT in config.h, or
//  override it from the command line (see web-flasher/build.sh):
//
//    SHS_VARIANT_MQTT_HA      Home Assistant over MQTT
//    SHS_VARIANT_SENSORBOARD  diy-sensor.org over HTTPS  (short workshop)
//    SHS_VARIANT_DISPLAY      display + serial only, no networking
//
//  Per-device configuration is NOT compiled in: it lives in NVS and is edited
//  from the setup portal, so one flashed image serves every device. See
//  settings.ino and portal.ino.
//
//  Board:     "ESP32C6 Dev Module"  (Arduino-ESP32 core)
//  Libraries: GFX Library for Arduino, bsec2, BME68x Sensor library,
//             WiFiManager (tzapu), PubSubClient
//
//  NOTE: bsec2 ships no esp32c6 precompiled blob — copy src/esp32c3/libalgobsec.a
//  to src/esp32c6/ before building. See instructions/build_instructions.md §4.
// ============================================================================
#include "config.h"
// These headers must be visible before Arduino injects its auto-generated
// prototypes: any function signature naming one of their types (bsecOutputs,
// WiFiManagerParameter, esp_qrcode_handle_t) is otherwise prototyped against an
// unknown type. The prototypes land at the top of the merged translation unit,
// ahead of the include in the .ino that actually uses the type.
#include <bsec2.h>
#if USE_NETWORK
#include <WiFiManager.h>
#endif
#if USE_DISPLAY
#include <qrcode.h>   // Espressif QR encoder, bundled with the ESP32 core
#endif

void setup() {
  Serial.begin(115200);
  delay(100);
  Serial.println("\nSmart Home Sensor starting (ESP32-C6 + BME680 / BSEC2)");

  // Settings first: the display title, the sensor's temperature offset and the
  // AP name all read from them.
  loadSettings();
  Serial.printf("Device: %s (%s)\n", settings.deviceName, settings.deviceId);

  displayInit();
  displayStatus("Detecting...", COLOR_INFO);

  // Must run before the sensor comes up: it blocks for the detection window,
  // and BSEC's sampling clock should not be started and then stalled.
  bool doubleReset = detectDoubleReset();

  if (bme680Init()) {
    Serial.println("BME680 + BSEC initialized");
    displayStatus("Stabilizing", COLOR_INFO);
  } else {
    Serial.println("BME680 / BSEC init failed");
    // Leave the specific error from checkBsecStatus() on the footer line.
    displayNoSensor();
  }

#if USE_NETWORK
  bool connected = wifiConnect();

  // Open the portal on a double reset, or whenever we cannot get online. Unlike
  // the battery-powered sister project there is no cost to being wrong here:
  // the device is on mains, and the portal keeps sampling BSEC while it waits.
  bool wasCommissioned = false;
  if (doubleReset || !connected) {
    runCommissioningPortal();
    displayResume();
    wasCommissioned = true;
    // Credentials may have just been entered — pick them up without a reboot.
    if (WiFi.status() != WL_CONNECTED) wifiConnect();
  }

  mqttConnect();
  sensorboardConnect();

#if USE_SENSORBOARD
  // Straight after setup, show where this board's readings will appear. A phone
  // camera turns the device ID into a dashboard without anyone transcribing it,
  // which is the step most likely to go wrong in a room of eighty boards.
  // Released automatically, so the readings screen takes over on its own.
  if (wasCommissioned) {
    char url[128];
    snprintf(url, sizeof(url), "%s%s", DASHBOARD_URL_FULL, settings.deviceId);
    Serial.printf("Dashboard: %s\n", url);
    displayQr(url, 20000);
  }
#else
  (void)wasCommissioned;
#endif
#else
  (void)doubleReset;
  Serial.println("Display-only build — no networking");
#endif
}

void loop() {
  bme680Run();    // samples when due (~3 s) and fires the data callback,
                  // which publishes to whichever backend is compiled in
  wifiLoop();     // re-associates in the background if the link drops
  mqttLoop();     // keeps the broker connection alive / reconnects
  displayTick();  // drives the Wi-Fi blink animation
}

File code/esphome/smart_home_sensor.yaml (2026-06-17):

# ============================================================================
#  Smart Home Sensor — ESPHome variant (ALTERNATIVE build)
#
#  This is the alternative firmware to the Arduino sketch in ../shs_modular/.
#  It exposes the same BME680 / BSEC2 metrics to Home Assistant, but uses
#  ESPHome's native API (auto-discovered by HA — no MQTT broker required).
#
#  Trade-off: ESPHome is the simplest path for students and the most idiomatic
#  for Home Assistant, but it does NOT reproduce the custom ST7789 dashboard UI
#  from the Arduino build 1:1. A minimal display block is provided below; the
#  rich coloured layout lives only in the Arduino variant.
#
#  Usage (Home Assistant ESPHome add-on or `esphome run`):
#    1. Copy this file into your ESPHome config directory.
#    2. Create a `secrets.yaml` with: wifi_ssid, wifi_password, ap_password.
#    3. Install / flash, then accept the device HA auto-discovers.
#
#  Board: Waveshare ESP32-C6-LCD-1.3  (ESP32-C6, Arduino framework)
# ============================================================================
esphome:
  name: smart-home-sensor
  friendly_name: Smart Home Sensor

esp32:
  board: esp32-c6-devkitc-1
  variant: esp32c6
  framework:
    type: arduino   # bme680_bsec2 requires the Arduino framework

logger:

# Native Home Assistant API — HA auto-discovers this device (no MQTT broker).
api:

ota:
  - platform: esphome

wifi:
  ssid: !secret wifi_ssid
  password: !secret wifi_password
  # Captive-portal fallback if the saved network is unreachable.
  ap:
    ssid: "Smart-Home-Sensor-Setup"
    password: !secret ap_password

captive_portal:

# ---------------------------------------------------------------------------
#  BME680 over I2C  (SDA=GPIO3, SCL=GPIO2 — avoid GPIO16/17 = UART0)
# ---------------------------------------------------------------------------
i2c:
  sda: GPIO3
  scl: GPIO2
  scan: true

# BSEC2 air-quality processing. The component downloads the BSEC2 library and
# applies its own calibration; the state is persisted to flash automatically.
bme680_bsec2:
  address: 0x76          # 0x77 on some modules — check the i2c scan in the log
  # Indoor air-quality use; "lp" = low power (3 s) sample rate.
  sample_rate: lp
  # Self-heating compensation — equivalent to TEMP_OFFSET_C in the Arduino build.
  # Calibrate: run ~20-30 min, then set to (reported - real thermometer).
  temperature_offset: 5.0

sensor:
  - platform: bme680_bsec2
    temperature:
      name: "Temperature"
      id: temperature
    humidity:
      name: "Humidity"
      id: humidity
    pressure:
      name: "Pressure"
    iaq:
      name: "IAQ"
      id: iaq
    co2_equivalent:
      name: "CO2 equivalent"
      id: co2
    breath_voc_equivalent:
      name: "Breath VOC equivalent"

text_sensor:
  - platform: bme680_bsec2
    iaq_accuracy:
      name: "IAQ Accuracy"

# ---------------------------------------------------------------------------
#  Optional minimal display (ST7789 240x240 over SPI).
#  Shows the headline values; not a 1:1 copy of the Arduino UI. Remove this
#  whole block if you do not want a display.
# ---------------------------------------------------------------------------
spi:
  clk_pin: GPIO7
  mosi_pin: GPIO6

output:
  - platform: gpio
    pin: GPIO22
    id: backlight
light:
  - platform: binary
    name: "Display Backlight"
    output: backlight
    restore_mode: ALWAYS_ON

display:
  - platform: st7789v
    model: Custom
    height: 240
    width: 240
    offset_height: 80   # 240x240 panel on 240x320 GRAM; 80px shift needed at rotation 270
    offset_width: 0
    cs_pin: GPIO14
    dc_pin: GPIO15
    reset_pin: GPIO21
    rotation: 270
    update_interval: 5s
    lambda: |-
      it.printf(10, 6,   id(roboto), "Smart Home Sensor");
      it.printf(10, 40,  id(roboto), "IAQ:  %.0f",     id(iaq).state);
      it.printf(10, 70,  id(roboto), "CO2:  %.0f ppm", id(co2).state);
      it.printf(10, 100, id(roboto), "Temp: %.1f C",   id(temperature).state);
      it.printf(10, 130, id(roboto), "Hum:  %.1f %%",  id(humidity).state);

# A font is required for display:. Provide any TTF in your ESPHome config dir.
font:
  - file: "gfonts://Roboto"
    id: roboto
    size: 20

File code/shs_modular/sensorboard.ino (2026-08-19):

// ============================================================================
//  sensorboard.ino — publish readings to a diy-sensor.org instance over HTTPS.
//
//  The ingestion contract is one POST per reading:
//
//    POST /sensor/measurement
//    X-API-Key: <apiKey>            (optional; makes the device persistent)
//    {"device_id": "...", "write_key": "...", "project": "...", "name": "...",
//     "sensors": {"temperature": {"value": 21.4, "unit": "C"}, ...}}
//
//  The server assigns the timestamp on receipt — clients cannot supply one, and
//  sending a "timestamp" field is an error rather than an ignored extra.
//
//  Unlike the battery-powered sister project, this device is always on and
//  keeps its reading in RAM, so a failed POST is not a measurement lost
//  forever — the next one is only a minute away. The retry logic is still
//  worth having for a flaky AP, but it is deliberately short: blocking the
//  loop for a minute would stall BSEC's 3 s sampling cadence.
// ============================================================================
#include "config.h"

#if USE_SENSORBOARD
#include <WiFi.h>
#include <HTTPClient.h>
#include <WiFiClientSecure.h>

static const uint8_t  SEND_ATTEMPTS   = 2;
static const uint32_t SEND_BACKOFF_MS = 1500;
static const uint32_t HTTP_CONNECT_MS = 8000;   // HTTPClient's 5 s default is
static const uint32_t HTTP_TIMEOUT_MS = 10000;  // short for a TLS handshake

static uint32_t lastSend = 0;

// Append "key":{"value":v,"unit":"u"} to the sensors object, skipping NaN.
// *first tracks whether a separating comma is needed.
static void appendSensor(String &json, const char *key, float value,
                         int decimals, const char *unit, bool *first) {
  if (!isValidFloat(value)) return;
  if (!*first) json += ",";
  json += "\"";
  json += key;
  json += "\":{\"value\":";
  json += String(value, (unsigned int)decimals);
  if (unit && unit[0]) {
    json += ",\"unit\":\"";
    json += unit;
    json += "\"";
  }
  json += "}";
  *first = false;
}

static String buildPayload(const SensorPacket &p) {
  String json = "{";
  json += "\"device_id\":\"" + String(settings.deviceId) + "\",";
  json += "\"name\":\"" + String(settings.deviceName) + "\",";
  if (settings.writeKey[0]) {
    json += "\"write_key\":\"" + String(settings.writeKey) + "\",";
  }
  // Omit the key entirely when unset — an ungrouped device is valid, an empty
  // project string is not.
  if (settings.project[0]) {
    json += "\"project\":\"" + String(settings.project) + "\",";
  }
  json += "\"sensors\":{";

  bool first = true;
  // IAQ is only meaningful once BSEC says so, but the accuracy level is sent
  // regardless — it is what explains a missing or implausible IAQ on the
  // dashboard during the first hours of calibration.
  appendSensor(json, "iaq",             p.iaq,                0, "",    &first);
  appendSensor(json, "iaq_accuracy",    (float)p.iaqAccuracy, 0, "",    &first);
  appendSensor(json, "co2_equivalent",  p.co2,                0, "ppm", &first);
  appendSensor(json, "voc_equivalent",  p.voc,                2, "ppm", &first);
  appendSensor(json, "temperature",     p.temperature,        2, "C",   &first);
  appendSensor(json, "humidity",        p.humidity,           1, "%",   &first);
  appendSensor(json, "pressure",        p.pressure,           1, "hPa", &first);
  appendSensor(json, "wifi_rssi",       (float)WiFi.RSSI(),   0, "dBm", &first);

  json += "}}";
  return json;
}

// One delivery attempt. Returns the HTTP status, a negative HTTPClient error
// code, or -1 if there is no link to send over.
static int postPayload(const String &json) {
  if (WiFi.status() != WL_CONNECTED) return -1;

  WiFiClientSecure tls;
  WiFiClient       plain;
  HTTPClient http;

  bool https = strncmp(settings.apiUrl, "https:", 6) == 0;
  if (https) {
    // No cert bundle is pinned: the workshop's threat model is a shared class
    // WiFi, and the payload is public sensor data. TLS still protects the
    // API and write keys in transit from casual observation.
    tls.setInsecure();
    if (!http.begin(tls, settings.apiUrl)) return -1;
  } else {
    if (!http.begin(plain, settings.apiUrl)) return -1;
  }

  http.setConnectTimeout(HTTP_CONNECT_MS);
  http.setTimeout(HTTP_TIMEOUT_MS);
  http.addHeader("Content-Type", "application/json");
  if (settings.apiKey[0]) http.addHeader("X-API-Key", settings.apiKey);

  int code = http.POST(json);
  http.end();
  return code;
}

// 201 = the device claimed its ID (first write), 200 = stored on an existing
// device. Anything else means the measurement did not land.
static bool isAccepted(int code) {
  return code == 200 || code == 201;
}

// Negative codes are transport failures (DNS, TLS, timeout, dropped link) and
// are worth another go. So are 429 and 5xx — the server is asking us to come
// back. Any other 4xx is our own malformed or unauthorised request: retrying
// produces the same rejection.
static bool shouldRetry(int code) {
  if (code < 0)    return true;
  if (code == 429) return true;
  return code >= 500;
}

// Explain the failures a student is actually likely to hit, rather than
// leaving them with a bare number.
static void explainCode(int code) {
  switch (code) {
    case 403:
      Serial.println("  403 invalid_write_key — this device ID is owned by a "
                     "different write key. If the board was flashed with a "
                     "different workshop image, ask the instructor to free the ID.");
      break;
    case 401:
      Serial.println("  401 — the API key was missing or rejected.");
      break;
    case 429:
      Serial.println("  429 — rate limited. The publish interval may be too short.");
      break;
    case 400:
      Serial.println("  400 — the server rejected the payload.");
      break;
    default: break;
  }
}

// ---- Public API -----------------------------------------------------------

void sensorboardConnect() {
  Serial.printf("diy-sensor: publishing to %s as '%s' every %u min\n",
                settings.apiUrl, settings.deviceId, settings.publishIntervalMin);
  if (settings.project[0]) Serial.printf("diy-sensor: project '%s'\n", settings.project);
  Serial.printf("diy-sensor: dashboard at %s%s\n", DASHBOARD_URL_PREFIX, settings.deviceId);
}

// Returns the HTTP code of the last attempt, or -1 if there was no link.
int sensorboardSend(const SensorPacket &p) {
  String json = buildPayload(p);
  int code = -1;

  for (uint8_t attempt = 1; attempt <= SEND_ATTEMPTS; attempt++) {
    code = postPayload(json);
    Serial.printf("POST attempt %u/%u -> %d\n", attempt, SEND_ATTEMPTS, code);

    if (isAccepted(code)) {
      displaySetMqttStatus(true);
      return code;
    }
    explainCode(code);
    if (!shouldRetry(code) || attempt == SEND_ATTEMPTS) break;
    delay(SEND_BACKOFF_MS);
  }

  displaySetMqttStatus(false);
  return code;
}
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

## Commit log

2026-06-12 Scaffold smart home sensor workshop
    Build out the workshop repo (modelled on hpi_smart_plants) for an always-on,
    USB-powered BME680 air-quality sensor on the Waveshare ESP32-C6-LCD-1.3 that
    reports to Home Assistant.
    - code/shs_modular/: modular Arduino firmware (display + BSEC2 + WiFiManager +
    MQTT auto-discovery), refactored from the original test_wv_display sketch
    - code/esphome/: ESPHome variant (native HA API) as an alternative build
    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
2026-06-15 Added 3D source and export files
    [SmartHomeCube-Lid.obj, SmartHomeCube-Main.obj, SmartHomeCube.FCStd]
2026-06-15 improved housing
    [SmartHomeCube-Lid.3mf, SmartHomeCube-Lid.obj, SmartHomeCube-Main.3mf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]
2026-06-16 added lid with offset
    [SmartHomeCube-Lid_w_offset.3mf]
2026-06-17 improved housing main body
    [SmartHomeCube-Main.3mf, SmartHomeCube.FCStd]
2026-08-19 Move per-device configuration from config.h into NVS
    A web-flashed binary cannot carry per-device values in a header: every
    student would need a recompile, which is exactly what the flasher is
    meant to avoid. Settings now live in NVS and are edited from the setup
    portal, so one image serves every device.
    config.h keeps only what genuinely belongs at compile time — the pin
    map, the build variant, and the DEFAULT_* values applied on first boot.
    It carries no credentials any more, so it is committed rather than
    gitignored and a fresh clone builds as-is. Workshop credentials move to
    the gitignored workshop_secrets.h.
    Device identity is deliberately not a setting. The device ID comes from
    the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
    [config.h, settings.ino]
2026-08-19 Restore Home Assistant MQTT discovery, make the mode selectable
    d11b1d9 "minor updates" replaced the discovery implementation with flat
    per-metric topics, while README, build_instructions and CLAUDE.md all
    went on promising auto-discovery. Restore it from bdad401 and keep what
    the flat version added on top (TLS client, NTP timestamp).
    Rather than picking one, the behaviour is now a runtime setting:
    DISCOVERY retained configs + one JSON state topic (default)
    FLAT one plain topic per metric, for non-HA consumers
    BOTH flat topics, with discovery configs pointing at them
    Switching away from a discovery mode now clears the retained configs.
    They outlive the device that publi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
    [mqtt.ino]
2026-08-19 Add the diy-sensor.org backend
    Publishes one POST per reading to the ingestion endpoint: device_id,
    write_key, optional project and name, and the BSEC outputs as
    {"value": ..., "unit": ...} pairs. NaN metrics are omitted rather than
    sent as null, since BSEC produces nothing until it has warmed up.
    Retries are deliberately shorter than in the battery-powered sister
    project. There a failed POST lost the measurement forever, because deep
    sleep destroyed it; here the device is always on and the next reading is
    a minute away, while blocking the loop would stall BSEC's 3 s sampling
    cadence.
    The failures students actually hit — 403 on a device ID owned by another
    write key, 401, 429 — are exp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
    [sensorboard.ino]
2026-08-19 Add the setup portal, double-reset entry, and three-variant wiring
    One source tree now produces three images, selected by SHS_VARIANT in
    config.h or overridden with -D from the command line: Home Assistant over
    MQTT, diy-sensor.org over HTTPS, and a display-only build with no
    networking at all.
    The portal is the piece that makes a flashed binary usable. Beyond Wi-Fi
    credentials it edits every runtime setting (filtered per variant, so no
    broker fields appear in the sensorboard image), shows live BME680
    readings with the IAQ accuracy spelled out, and offers a send test that
    reports what the backend actually answered. It stays open in AP+STA mode
    after Wi-Fi connects, so that test runs over th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
    [bme680.ino, display.ino, portal.ino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]
2026-08-19 Add the web flasher with a three-image picker
    Flashing from a browser removes the Arduino IDE, the core install, the
    library hunt and the BSEC blob workaround from a student's first hour —
    which is most of what a short workshop does not have time for.
    The picker swaps the manifest on the install button, so one page offers
    all three builds. The workshop image is listed first and preselected.
    build.sh produces all three merged images from the same sources, and
    recreates the missing esp32c6 BSEC blob when a library update has
    removed it — that failure otherwise appears as a bare linker error with
    nothing pointing at the cause. Verified end-to-end: it builds a 4 MB
    merged image for the sen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
2026-08-19 Report every 5 minutes, configured in minutes
    Seconds were the wrong unit to expose. Indoor air quality does not move
    fast enough to need a reading every minute, and the cost of a short
    interval is not paid by the device that sets it: diy-sensor.org charges
    its write budget per credential and per stored value, so every device
    sharing the workshop API key spends from the same bucket. At 8 sensors
    per reading, 80 devices at 60 s came to 10.7 rows/s against a 3 rows/s
    budget — it would have looked fine during setup, then started failing
    once everyone was publishing steadily. At 5 minutes the same room costs
    2.1 rows/s.
    The display still refreshes every ~3 s, so the room still gets immediate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
    [config.h, mqtt.ino, portal.ino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]
2026-08-19 Correct what the published salt actually exposes
    Both notes claimed anyone with the workshop image could derive any
    device's write key from its public device ID. That is wrong, and wrong in
    the direction that discourages the mitigation that does matter.
    The HMAC covers the full 48-bit MAC; the device ID carries only the low
    32, and because of how the core packs the efuse MAC those are the OUI
    plus one NIC byte — the predictable part. A device ID leaves 65,536
    candidates and no offline way to test one, so each guess costs a POST:
    hours per device under the per-IP limits, and loud in the ingest log.
    What does defeat it is proximity. The Wi-Fi station MAC is the same efuse
    MAC, broadcast in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
    [settings.ino]
2026-08-19 Split the diy-sensor build into keyed and keyless images
    The workshop image has an end date; the hardware does not. Shipping only
    a keyed build meant every board became inert when the key was withdrawn,
    so there are now four images: European Impact Sprint (keyed, withdrawn
    26 Aug 2026) and a plain keyless diy-sensor build that stays on the page
    and publishes to the same dashboard under the same device ID.
    Both are SHS_VARIANT=2 and differ only in whether workshop_secrets.h is
    compiled in, so one build.sh run produces both.
    Fixes a leak in the process: the include was not gated on
    USE_SENSORBOARD, and resetSettingsToDefaults() copies DEFAULT_API_KEY
    regardless of variant — so the workshop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
    [config.h, portal.ino, settings.ino]
2026-08-19 Only promise what the takedown alone delivers
    The notice said devices still running the sprint image stop publishing on
    26 August, and that readings are removed after 48 hours. Neither follows
    from removing the image from this page: the first needs the key revoked,
    the second needs PERSISTENT_DEVICES=false on the server policy. Both are
    operational choices a participant cannot see, and one of them is not
    applied yet.
    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
2026-08-19 Describe retention as it actually works
    Expiry is idle-based per device, not a rolling window over readings: the
    sweep deletes device rows whose last_seen_at is past the cutoff and
    cascades to their measurements. A device that keeps publishing therefore
    keeps its whole history, and the dashboard is only "temporary" for the
    devices that stop. Calling the whole thing disposable was wrong in the
    other direction from the claim it replaced.
    Also records the ordering trap next to the policy that triggers it:
    `persistent` is stamped on the device row at claim time and the sweep
    reads that column, so PERSISTENT_DEVICES=false applied after the first
    board claims leaves those devices persistent forev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
2026-08-19 Fix the truncated API key and the readings painting over setup
    Two failures from the first hardware flash.
    **401 on every publish.** The workshop key is 51 characters and
    Settings::apiKey was char[48], so strlcpy silently cut it to 47 and the
    device sent a key that could never match. A curl test with the same key
    succeeded, which is what made this look like a server problem: the
    truncation only exists on the device. The field sizes are now named
    constants with static_asserts against the compiled-in defaults, so an
    oversized credential fails the build with a message naming the field
    instead of becoming a 401 on the workshop floor.
    Credentials compiled into an image are also reapplied at eve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
    [config.h, display.ino, portal.ino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]
2026-08-19 Setup-stage sensor status, honest link label, dashboard QR
    Three things the first real flash showed.
    **No sensor feedback during setup.** A dead BME680 looked identical to a
    working one until setup finished, which is the worst moment to find out.
    The setup screen now carries a sensor line (NOT FOUND / warming up /
    OK with the calibration level), refreshed while the portal runs, and the
    live page shows a red banner naming the four wires when the sensor is
    missing.
    **"MQ" on a diy-sensor device.** The label named a protocol that build
    does not speak; it now reads API there, and nothing at all on the
    display-only build. It was also red for the first five minutes of every
    boot, reporting a fai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
    [bme680.ino, config.h, display.ino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]
2026-08-19 Fix the corner collision, regrid the setup screen, add rotation
    **"API" overlapped the WiFi icon.** The corner was laid out around a
    two-character label at a fixed x; three characters ran into the icon and
    off the 240 px edge. The label now sits to the left of the icon and is
    right-aligned against it, so its width no longer matters: MQ occupies
    177..201 and API 165..201, both with a 6 px gap to an icon spanning
    207..235.
    **The setup screen mixed two layouts.** Three fields put the caption
    above the value; the sensor line put it beside. All four now go through
    one drawPortalField() on a 42 px pitch, so the grid is defined once
    instead of per field, and the sensor row is just the fourth entry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
    [config.h, display.ino, portal.ino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]
2026-08-19 Default the display to rotation 1
    The settings version is deliberately not bumped. A fresh board has no
    stored settings and picks this up; one that has already been set up keeps
    its own rotation, which is the point of the setting existing. Bumping
    would re-seed every field to force a cosmetic default, taking the device
    name with it.
2026-08-20 Add a workshop load-test script
    Sends what the firmware sends — same eight values, same payload shape,
    same cadence — so the server config can be exercised before a room of
    students does it. It is aimed at the limits that only appear with many
    devices on one credential: the write budget charged per key and per
    stored value, the new-devices-per-hour cap that a class behind one NAT
    address hits in its first hour, and the burst that absorbs the first
    synchronised round and can hide a wrong rate until it drains.
    It insists on the real workshop key rather than generating one, because
    the budget is bucketed by key hash: a test key gets its own bucket and
    would report a healthy run that proves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
2026-08-20 added updated 3D-print files
    [SmartHomeCube-Inlay.3mf, SmartHomeCube-Inlay_top.3mf, SmartHomeCube-Lid.3mf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]
2026-08-20 Remove the workshop load-test script
    The infrastructure test it existed for is done: 1200/1200 requests
    accepted across 24 rounds, no limit hit. The retention side is being
    verified by letting the devices it created expire on their own, so the
    cleanup script it generated is not wanted either.
    Reverts e20a83d. The commit itself stays in history, since it is already
    on main and rewriting the default branch would be worse than a revert.
2026-08-21 added mikrocontroller 3D-model and a assembly animation
    [ESP32-C6-LCD-1.3-M.FCStd, SmartHomeCube.FCStd]
2026-08-24 Added assembly gif
2026-08-24 Serve ESP Web Tools from this site instead of a CDN
    The page loaded install-button.js from unpkg, so every visitor's IP
    address went to a third party before they clicked anything: a data
    transfer to describe in a privacy notice, in exchange for nothing.
    Copying the entry point alone would not have worked. It is 2.8 KB and
    lazily import()s hashed sibling chunks, one per supported chip, so the
    page would have loaded normally and then failed when someone pressed
    Connect. All 26 files of the graph are vendored, and every one of the 63
    import specifiers across them now resolves locally.
    esp-web-tools 10.4.0, Apache-2.0, with the licence alongside it and the
    fetch-and-verify procedure in vendor/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
2026-08-24 Fix documentation left behind by the runtime-config rework
    A consistency pass found stale text from before settings moved into the
    portal and the cadence changed from seconds to minutes.
    - The troubleshooting table still told students readings arrive "up to a
    minute" after the default became five, so a working device looked
    broken for four minutes longer than the page allowed for. It now
    distinguishes the test reading, which appears at once, from the next
    scheduled one.
    - The temperature offset was still named TEMP_OFFSET_C, a macro that no
    longer exists under that name and is no longer what a user edits.
    - 201 was explained as "your device claimed its ID", which is true only
    of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
2026-08-24 Fix the workshop-date wording, BSEC path, and reflash advice
    Three more from the consistency review, two of which I had wrongly
    cleared on the first pass.
    The quick reference told people to cd into BSEC2_Software_Library while
    every other document and build.sh use bsec2. I missed it because I
    grepped instructions/*.md, which does not descend into
    instructions/quick_reference/. Both now name bsec2 and say how to find
    the folder if it is called something else: look for the one containing
    esp32c3/libalgobsec.a.
    The flasher page told participants a reflash keeps the same device ID
    without mentioning the write key that makes it true. Following it would
    produce a device rejected by the dashboard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
2026-08-24 Document why IAQ accuracy falls back, and fix the offset formula
    Two things a device in the room raised.
    **Accuracy dropping 3 to 2 to 1** looks like a fault and is not one. The
    figure is BSEC's confidence in its own gas baseline, not a score for the
    reading, so a fall means the baseline stopped explaining what the sensor
    sees and is being rebuilt. background_information.md now says so and
    lists what causes it, including the one that hits during a workshop: the
    calibrated state is only written at accuracy 3 and then every six hours,
    so a run of reflashes and double-resets resumes from a stale baseline.
    **The calibration instruction was wrong**, in all four places it
    appeared. "Set the offs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
    [config.h]
2026-08-24 Let the Wi-Fi radio sleep again
    Modem sleep was disabled here for latency. That was the wrong trade on
    this device: the radio sits a few centimetres from the temperature sensor
    inside a closed enclosure, and keeping its front-end powered between
    beacons dissipates a few hundred milliwatts continuously. The heat lands
    on the one measurement the device exists to report.
    It also explains the offset drift. The 5 °C figure was characterised on
    the pre-networking sketch in code/legacy/test_wv_display/, which has no
    radio at all; a board running this firmware needed about 7.5 °C. Rather
    than raise the default to compensate for self-inflicted heat, the heat
    goes away and the 5 °C default stands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
    [wifi.ino]
2026-08-24 Restructure the workshop documentation
    Make the web-flasher path the default build guide and move the Arduino
    toolchain out of the way, so the documentation matches how the workshop
    actually runs.
    - build_instructions.md is now the standard guide: wiring, enclosure,
    browser flashing, setup portal, first readings. It absorbs
    short_workshop.md, which is removed.
    - build_instructions_extended.md holds the Arduino path: toolchain,
    BSEC blob, compile-time variants, MQTT/Home Assistant, ESPHome.
    - Drop the event-specific framing. Workshop images are described
    generically as builds carrying an event's defaults.
    - README reads as a project overview rather than participant
    instructions, an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
2026-08-25 Quick fixes before workshop
    Device ID: derive the 8-char suffix from a SHA-256 of the full 48-bit MAC
    instead of truncating the MAC. Truncation kept the Espressif OUI, so every
    board in a batch shared a prefix and differed only in the last digits.
    Setup portal: WiFiManager draws its Back button only behind a private flag, so
    its subpages dead-ended — inject a Back button into every page, along with a
    note that pages served off the board take a few seconds and a second tap only
    queues a second request. The reset pages say how to get back after the reboot,
    and the live page gains a Setup link in its header.
    Docs: record that the current enclosure covers the RESET button, so the
    double-rese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
    [config.h, portal.ino, settings.ino]
2026-08-25 Bump the flasher manifest versions for the rebuilt images
    The images change the device ID derivation and the setup portal's navigation,
    so every manifest gets a new version.
2026-08-25 Replace the assembly photos and rewrite the build steps around them
    The old wiring photos showed the Dupont wires soldered onto the front of
    the BME680, where they cross the component face and obstruct both the
    sensor and the upper inlay. The new sequence shows the wires threaded
    through the pad holes from the plain back side and bent flat so they leave
    the module sideways, in the plane of the board.
    - Wiring step now covers cutting/stripping the wires, threading and
    bending them, soldering on the labelled side, and plugging the sockets
    onto the board, with one photo per stage.
    - Enclosure step becomes a single ordered sequence: board and lower inlay
    seated, sensor into the upper inla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
2026-08-25 Correct the wiring line in the quick reference
    The one-pager still described soldering the wires onto the back of the
    BME680. Match the build instructions: the stripped ends go through the pad
    holes from the plain back and are soldered flat on the labelled front, so
    the wires leave the module sideways. Regenerates the 2-up PDF.
2026-08-25 Allow the device ID to be overridden in the portal
    The device ID is derived from the efuse MAC, which assumes the MAC is
    unique. Boards from some batches ship with a duplicated MAC, so two of
    them derive the same ID, publish to the same dashboard entry and
    overwrite each other's readings.
    The diy-sensor builds now take an optional device ID in the setup
    portal. It is normalised ([a-z0-9-], lower case, project prefix added
    when missing) and stored in NVS as an override applied on top of the
    derived value; blank returns to the derived ID. The write key stays
    derived from the MAC, so a board still owns the ID it claims.
    The settings version is not bumped: the new field needs no migration,
    and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
    [config.h, portal.ino, settings.ino]
2026-08-26 Retire the sprint image from the flasher page
    The European Impact Sprint is over, so its image is withdrawn as
    announced on the page. The picker drops that option and defaults to the
    standard diy-sensor.org build, and the notice explains what happens to
    boards already running the sprint image.
    The write-key warning gains the part that now matters: only the sprint
    image could recreate that key, so it must be copied out of the setup
    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
2026-09-09 3D model work in progress
    [SmartHomeCube-Lid.3mf, SmartHomeCube-Main.3mf, SmartHomeCube.FCStd]
2026-09-09 3D-model work in progress
    [SmartHomeCube-Inlay_mid.3mf, SmartHomeCube-Inlay_top.3mf, SmartHomeCube-Lid.3mf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]
2026-09-09 3D-models work in progress
    [SmartHomeCube-Main.3mf, SmartHomeCube.FCStd]
2026-09-09 Fix ESP32-C6 identity collisions
    [config.h, settings.ino]
2026-09-10 3D models updated
    [SmartHomeCube-Inlay.3mf, SmartHomeCube-Inlay_mid.3mf, SmartHomeCube-Inlay_top.3mf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]
2026-09-15 docs: add sensor test before enclosure assembly
2026-09-15 docs: add wiring photo and renumber instruction images
2026-09-15 uploaded wiring img
2026-09-15 docs: remove housing photo from sensor wiring step
2026-09-15 docs: align sensor checks and setup with firmware
2026-09-22 docs: add BME680 wiring sketch to quick reference
    Include a labelled six-pin connector diagram and rebuild the two-page A5 handout.
    Fixes #12
2026-09-22 docs: refine build guide and prepare HPI workshop flasher
    Clarify wiring and setup, correct device identity and reset guidance, and remove em dashes from the build instructions. Update the flasher sources for the HPI Makeruniverse Welcome Workshop and ignore local agent instructions.
    Fixes #13
    Fixes #14
2026-09-22 docs: restructure and redesign the quick reference
    Open the handout with a one-sentence description of what the device is
    and what it can connect to, so the sheet stands on its own.
    Rework the content:
    - Enclosure assembly now lists the part stack bottom to top, names the
    inlays, and describes how the lid goes on at an angle and that the
    closed lid covers RESET.
    - Troubleshooting collects the failure cases that were scattered through
    the build steps: no serial port, sensor not found, no setup network,
    failed test reading, no data on the dashboard yet.
    - The readings section distinguishes the QR code shown on the display
    from the one that links to the build instructions.
    Rework t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
2026-09-22 docs: keep the lid note with the assembly step
    Shorten the lid callout and hold callouts together across page breaks so
    the note sits on the same page as the part stack it belongs to, instead
    of opening the second page on its own. The wiring diagram gives up the
    width this needs.
2026-09-22 docs: spend the shortened assembly step on legibility
    Insulation between board and sensor is not optional — it is what keeps
    board heat off the sensor, and the temperature offset assumes it. Drop
    the qualifier.
    The shorter assembly step leaves room on the first page, so raise the
    body text and the wiring diagram back towards their earlier size.
2026-09-22 docs: add a quick reference footer and a two-per-sheet print file
    Foot the handout with the project URL, the documentation licence and the
    author, pinned to the bottom of the back page.
    Also emit quick_reference_a5_2up.pdf, the same handout with its pages
    duplicated as 1,1,2,2. Printed two per sheet and double-sided, each A4
    sheet carries two complete handouts that can be cut apart.
    Replace the ASCII arrow in the setup callout with the arrow character
    used everywhere else on the sheet.
